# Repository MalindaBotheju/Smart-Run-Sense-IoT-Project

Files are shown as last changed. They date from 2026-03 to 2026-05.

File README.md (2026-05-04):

# 🏃‍♂️ SmartRunSense: IoT-Based Environmental Monitoring and Prediction System 

<p align="center">
  
  
  
  
  
  
</p>

## 📖 Overview
Outdoor running provides cardiovascular and mental health benefits, but exposes runners to thermodynamic and respiratory stresses caused by environmental conditions like heat, humidity, particulate matter, and gaseous pollutants. SmartRunSense is an Internet of Things (IoT) system designed to optimize performance and reduce physiological risks by helping runners make informed decisions about when and where to train. 

The system combines real-time environmental sensing, cloud-based data storage, machine learning predictive analytics, and a companion mobile application to provide both current and forecasted environmental conditions. 

---

## 🗺️ System Architecture Diagram
The diagram below illustrates the comprehensive project structure and data connections, organizing the system into four distinct logical layers: Edge Hardware (Wearable and Smart Pole nodes with their shared sensor suite), Cloud Ingestion & Storage (Firestore acting as the central data hub), Cloud Processing (Google Cloud Run executing the scikit-learn Random Forest forecasting engine), and the Application Layer (Mobile App visualizing live and forecasted conditions).

<p align="center">
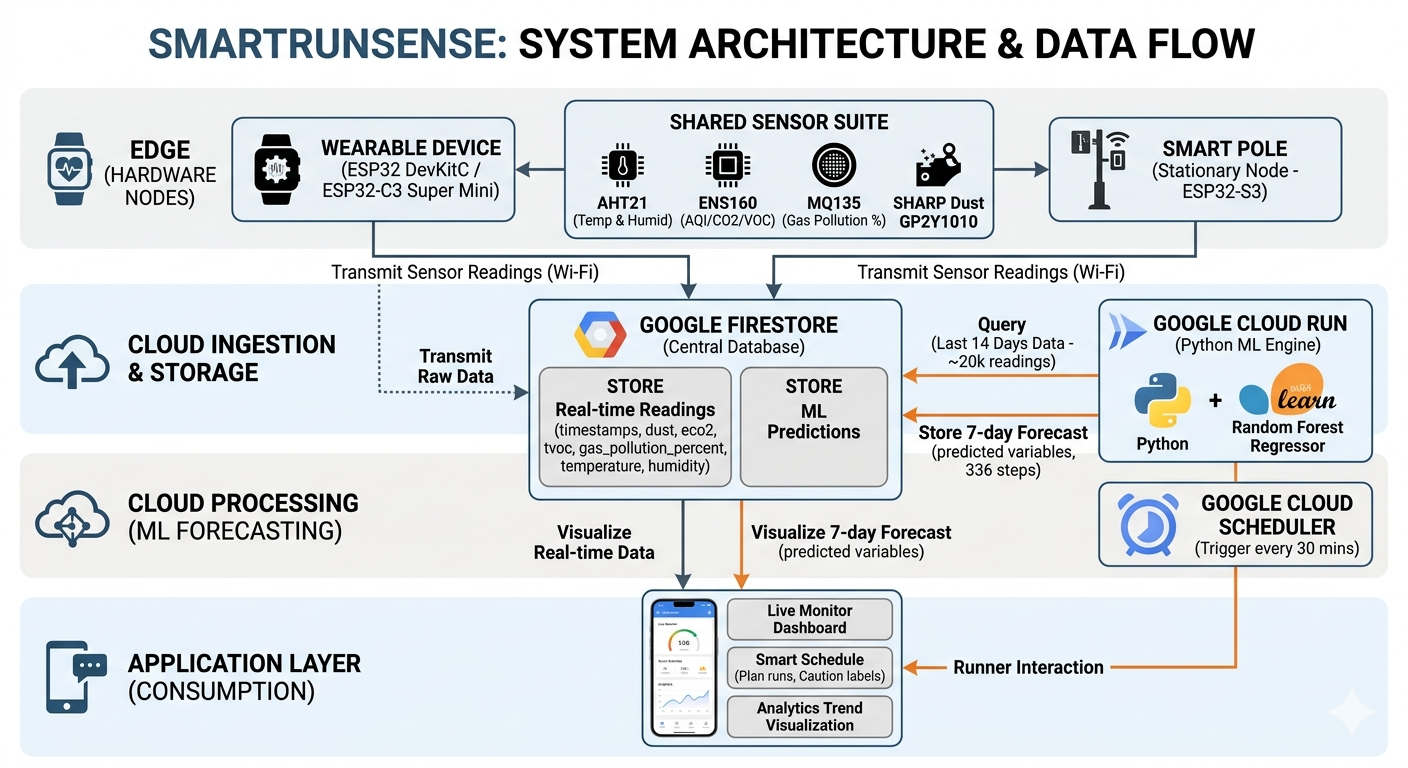
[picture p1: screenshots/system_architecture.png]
SmartRunSense System Architecture Diagram
  
</p>

---

## ✨ Key Features
* 📡 **Real-Time Monitoring:** Collects localized environmental data using wearable devices and stationary "Smart Poles".
* 🤖 **Machine Learning Forecasting:** Automatically predicts air quality and weather conditions 7 days into the future.
* 📱 **Mobile Application:** Provides a live sensor dashboards, historical analytics, and a "Smart Schedule" to plan the safest times to jog.

---

## 🛠️ Hardware Architecture

The system utilizes a dual-node hardware approach, consisting of mobile wearable devices and stationary monitoring nodes ("Smart Poles"). 

## ⌚ 1. Wearable Device
Designed for mobility, this node can be built using either an **ESP32 DevKitC** or a compact **ESP32-C3 Super Mini** microcontroller. 

<p align="center">
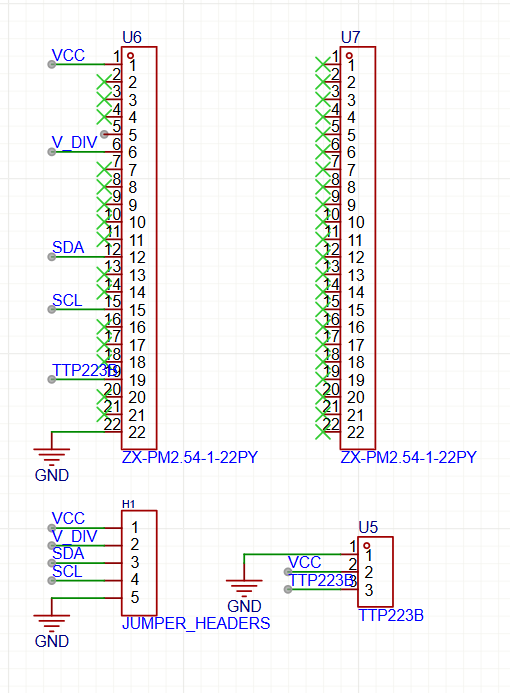
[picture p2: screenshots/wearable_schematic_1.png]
Wearable Schematic (Board-01)
  
  &nbsp;
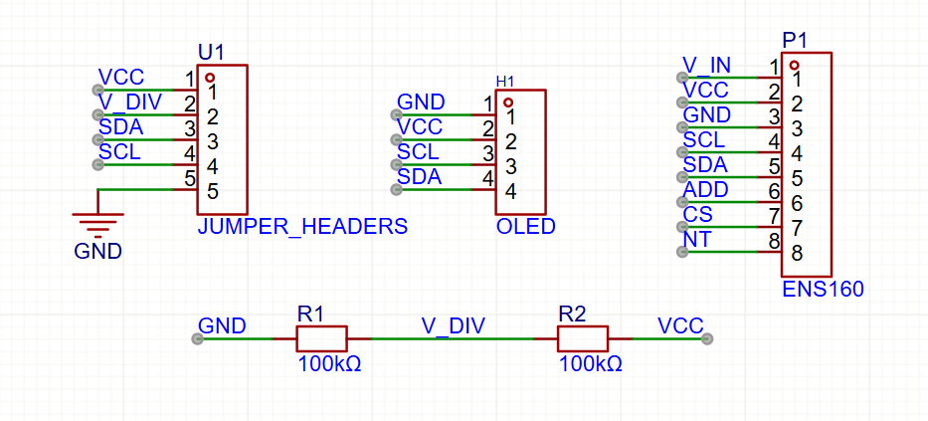
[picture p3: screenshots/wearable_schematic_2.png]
Wearable Schematic (Board-02)
  
  &nbsp;
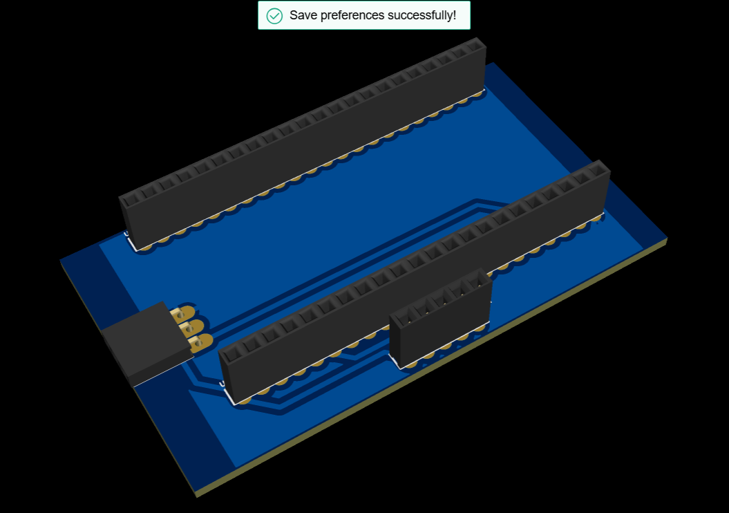
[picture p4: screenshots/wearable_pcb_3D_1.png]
Wearable PCB 3D View (Board-01)
  
  &nbsp;
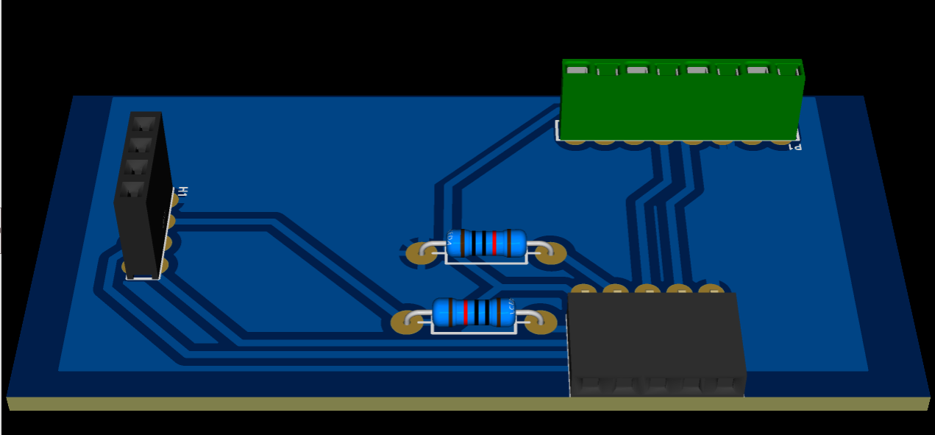
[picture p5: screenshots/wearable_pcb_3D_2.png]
Wearable PCB 3D View (Board-02)
  
  &nbsp;
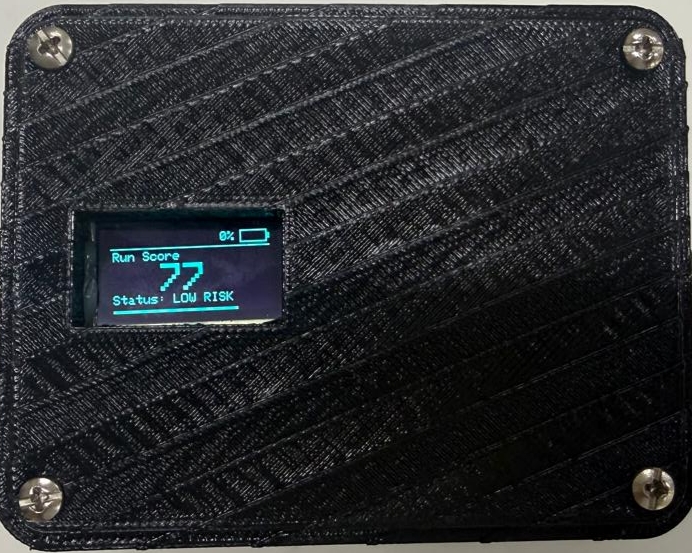
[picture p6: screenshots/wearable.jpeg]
Assembled Wearable Device
  
  &nbsp;
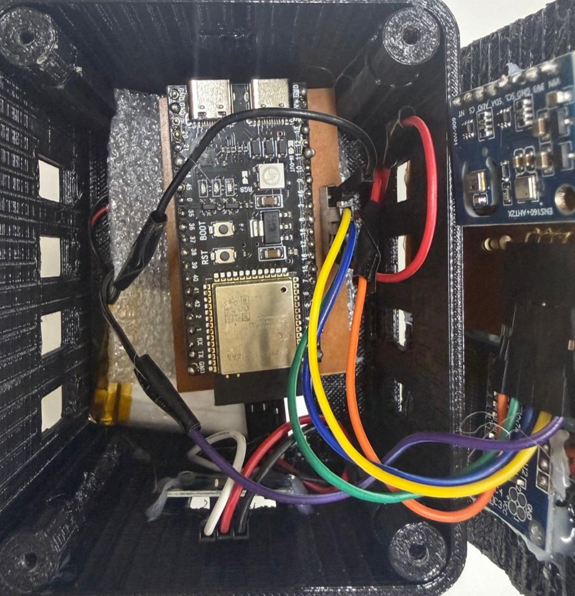
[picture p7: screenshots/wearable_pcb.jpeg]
Wearable PCB Layout
   
</p>

---

## 🗼 2. Smart Pole (Stationary Node)
Designed for continuous environmental monitoring at fixed locations (like running tracks or parks), this node is powered by a more robust **ESP32-S3** module.

<p align="center">
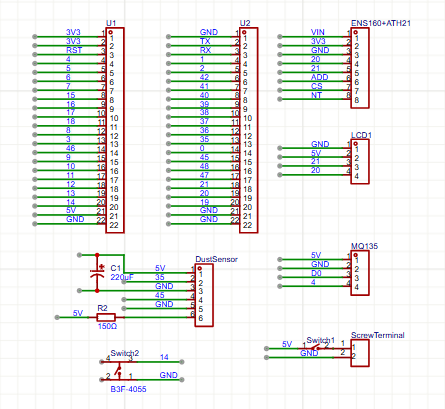
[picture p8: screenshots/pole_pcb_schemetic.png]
Smart Pole Schematic
  
  &nbsp;
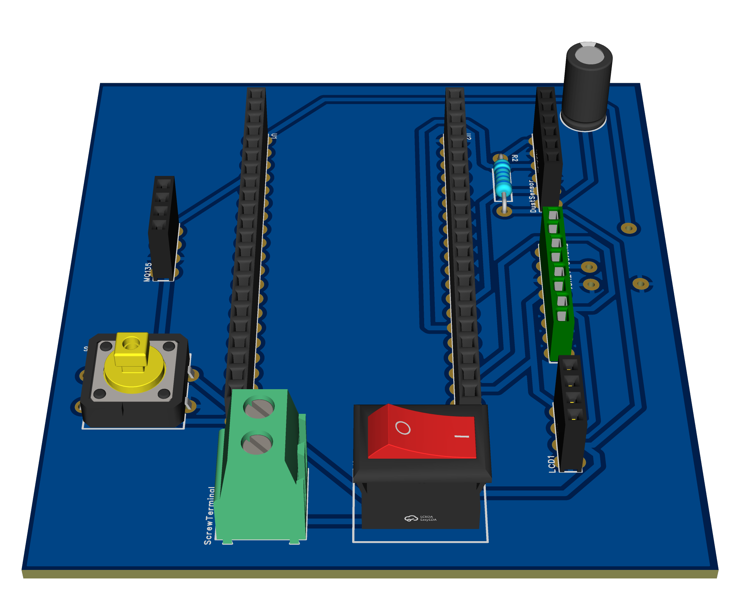
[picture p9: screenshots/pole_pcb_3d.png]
Smart Pole 3D PCB View
  
  &nbsp;
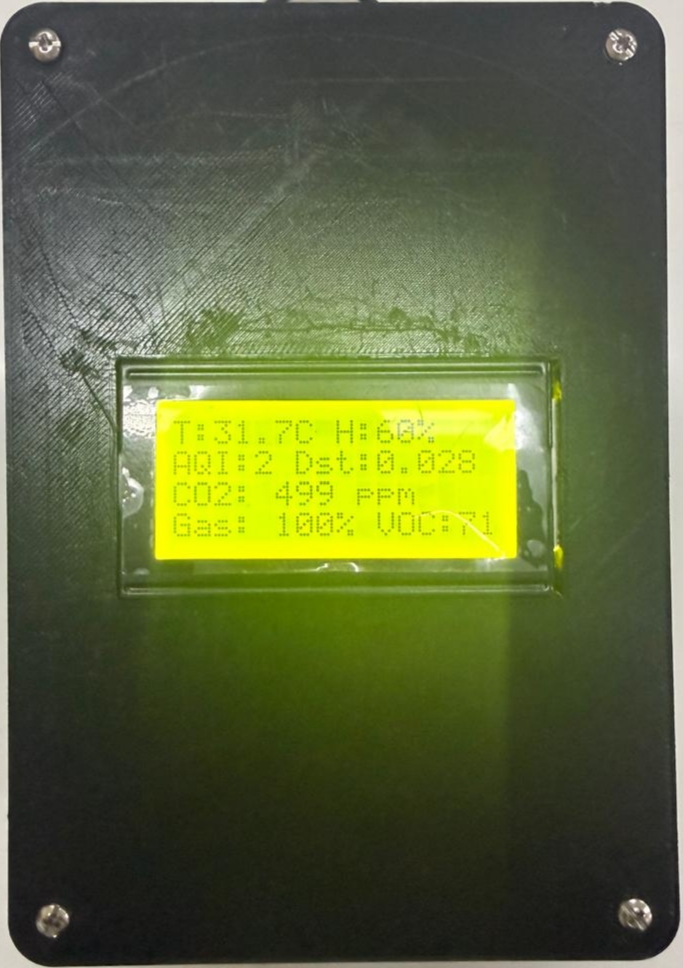
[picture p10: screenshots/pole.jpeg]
Assembled Smart Pole Device
  
  &nbsp;
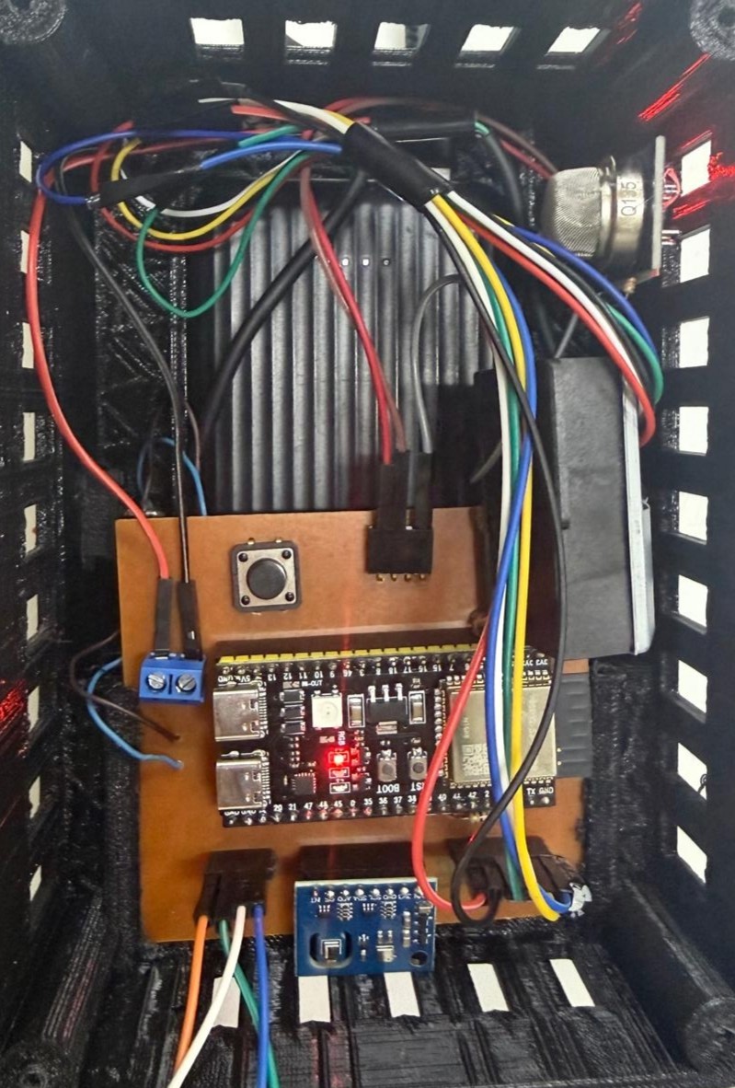
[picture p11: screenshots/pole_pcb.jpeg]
Smart Pole PCB Layout
  
</p>

---

Both the wearable and the Smart Pole devices interface with the following shared sensor suite and components:

## 🌡️ Sensors
* 🌬️ **ENS160 (Air Quality):** A self-calibrated digital sensor that measures the Air Quality Index (AQI), eCO2 (400-65,000 ppm), and Total Volatile Organic Compounds (TVOC).
* 💧 **AHT21 (Temperature & Humidity):** Factory-calibrated sensor measuring temperature (-40°C to +85°C) and relative humidity.
* 🏭 **MQ135 Gas Sensor:** An analog chemoresistive sensor used to measure general gas pollution intensity (0-100% scale), including Ammonia, NOx, Alcohol, Benzene, and Smoke. It uses a voltage divider circuit to safely interface the 5V sensor with the 3.3V ESP32.
* 💨 **SHARP GP2Y1010 Dust Sensor:** An optical sensor with an internal infrared LED and photodiode used to detect fine particles like dust, pollen, and smoke.

---

## 🧠 Machine Learning Forecasting Engine & ☁️ Cloud Infrastructure
A Python-based Cloud Run microservice acts as the forecasting engine.

* ⚙️ **Execution:** Triggered every 30 minutes by Google Cloud Scheduler.
<p align="center">
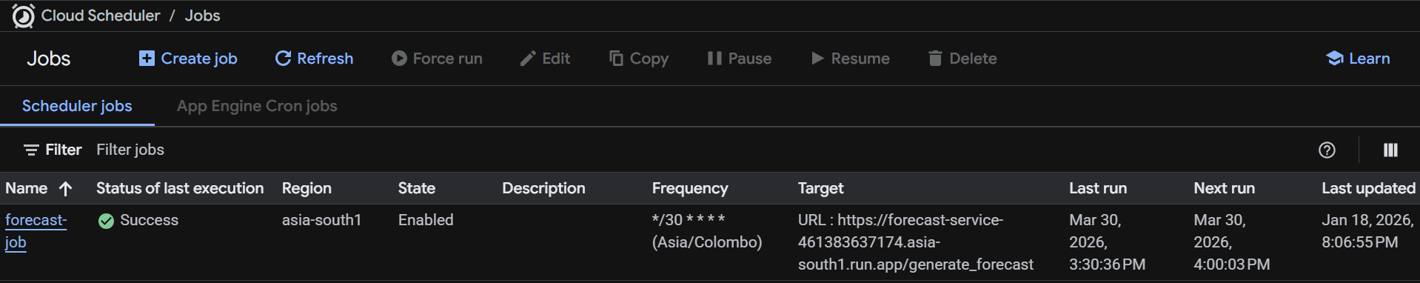
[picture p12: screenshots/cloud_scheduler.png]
Google Cloud Scheduler Configuration
  
</p>

* 📈 **Algorithm:** Uses a Random Forest Regressor (via scikit-learn) because it efficiently handles the highly non-linear nature of environmental data and trains in seconds using standard CPUs without requiring strict data scaling.
<p align="center">
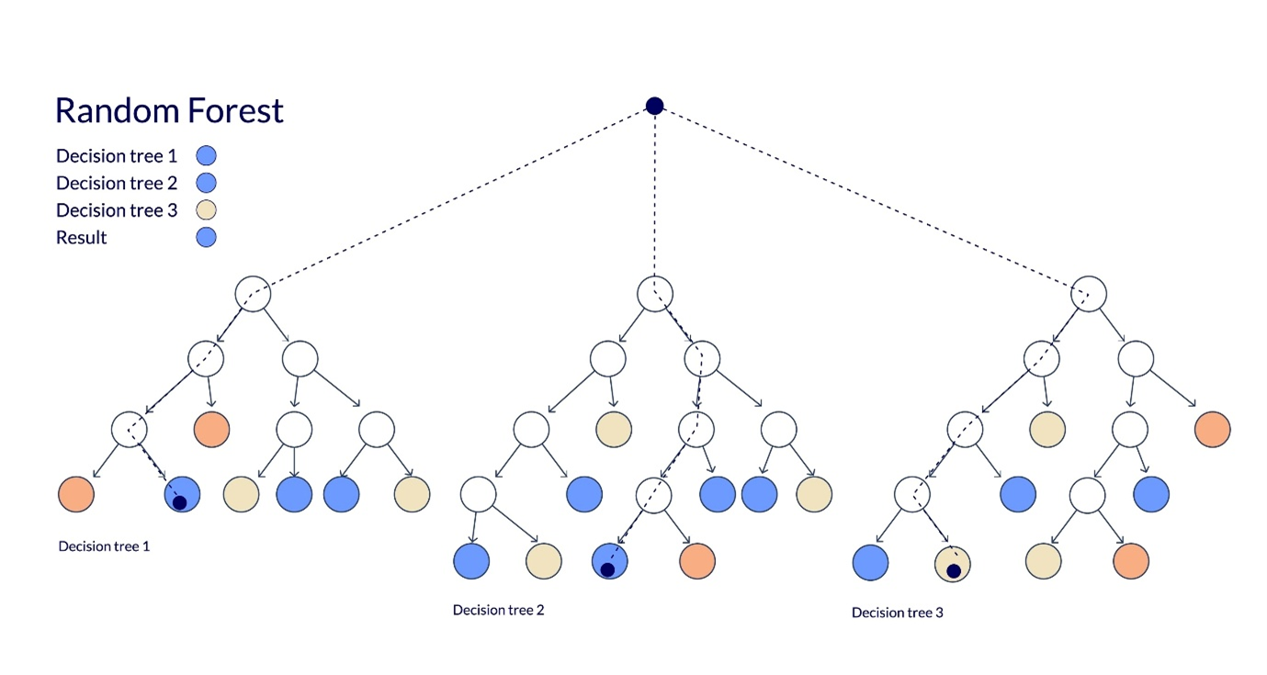
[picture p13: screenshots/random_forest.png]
Random Forest Algorithm Architecture
  
</p>

* 📊 **Data Scope:** The model queries the last 14 days (~20,000 readings) of data from Firestore to learn daily and weekly patterns.

* 🔮 **Output:** Generates predictions in 30-minute intervals for exactly 7 days into the future (336 distinct prediction steps per run). It predicts 7 variables simultaneously: Temperature, Humidity, Dust Density, AQI, TVOC, CO2, and Gas Pollution Percentage.

---

## 🗄️ Database
* 🔥 **Google Firestore:** Acts as the primary database, storing real-time sensor readings (e.g., timestamps, dust, eco2, tvoc, gas_pollution_percent, temperature, humidity) and the ML-generated predictions.
  
<p align="center">
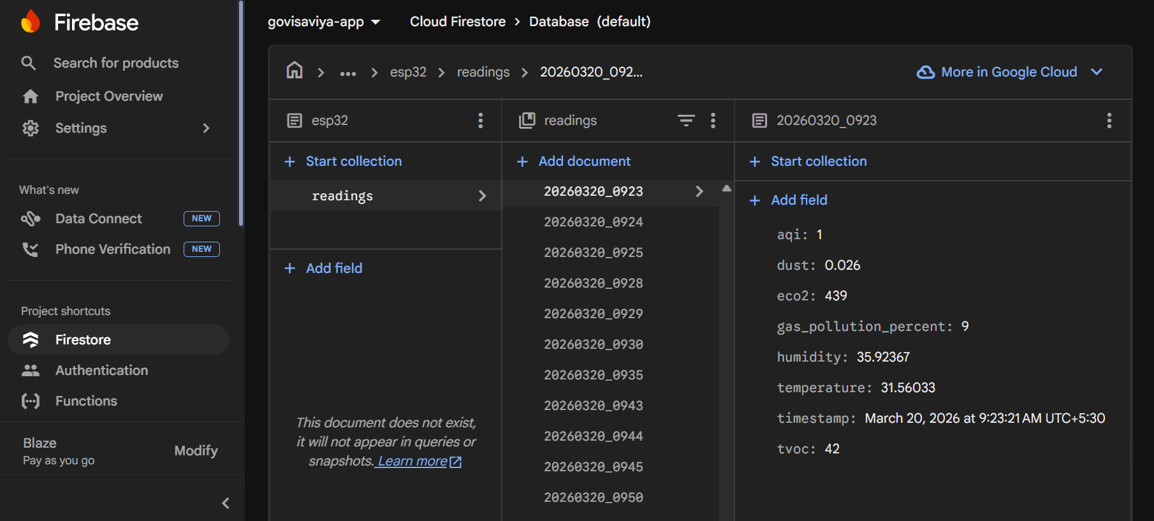
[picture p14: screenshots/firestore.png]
Google Firestore Database View
  
</p>

---

## 📱 Mobile Application
The mobile UI provides comprehensive data visualization for the end-user:

* 📊 **Live Monitor:** Displays real-time metrics including a summarized "Run Score" (e.g., 77% - LOW RISK) and individual sensor percentages.
* 📅 **Plan Your Activity (Smart Schedule):** Allows users to view upcoming days and flags specific time slots (e.g., "21:00 Caution Required - Pollution or heat levels elevated") to help them plan the best time to run.
* 📉 **Analytics:** Visualizes historical trends and insights, such as Dust and CO2 levels over time.
* 🌤️ **Forecast:** Displays the upcoming environmental predictions generated by the cloud microservice.

## 📸 App Screenshots

<p align="center">
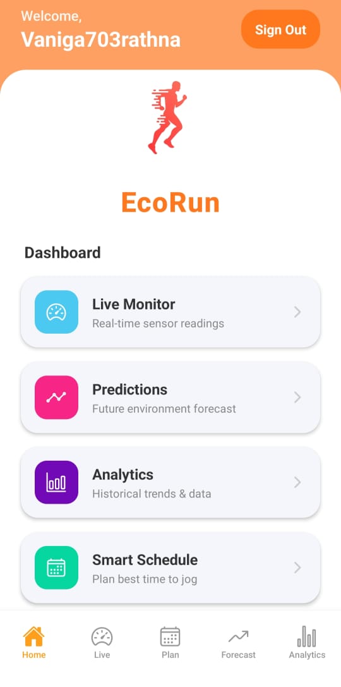
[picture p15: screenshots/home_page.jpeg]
Home Page
  
  &nbsp;
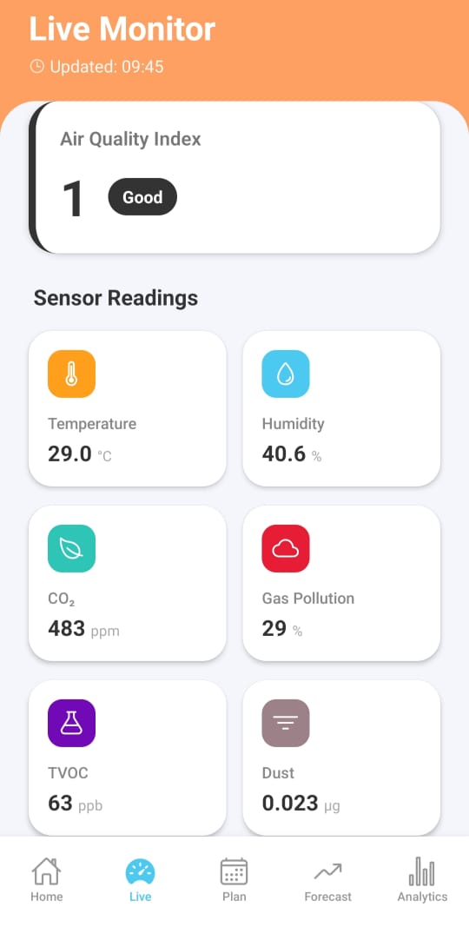
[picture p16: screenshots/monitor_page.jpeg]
Live Monitor
  
  &nbsp;
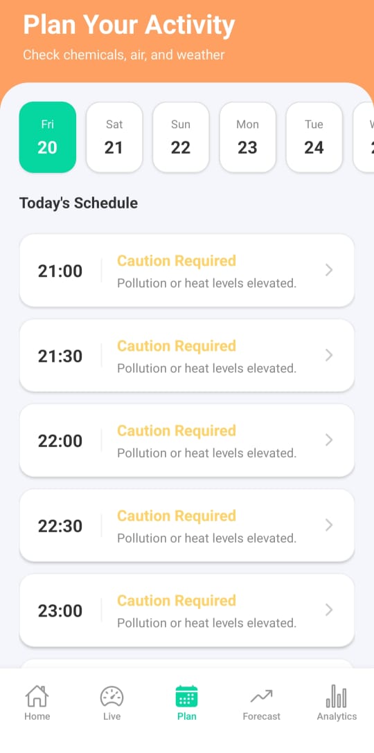
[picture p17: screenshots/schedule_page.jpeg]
Smart Schedule
  
  &nbsp;
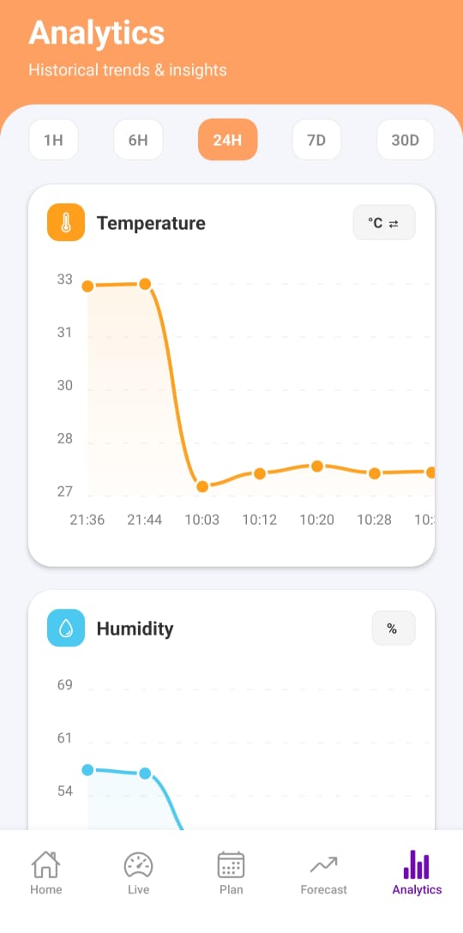
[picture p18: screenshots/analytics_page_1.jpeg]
Analytics Part 1
  
  &nbsp;
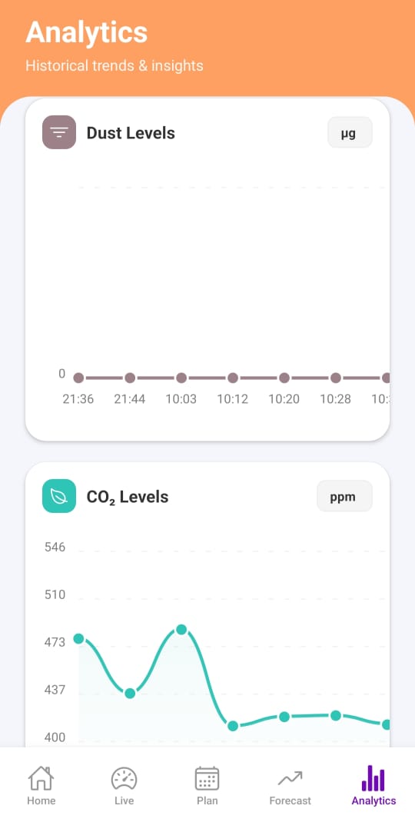
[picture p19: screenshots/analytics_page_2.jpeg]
Analytics Part 2
  
</p>

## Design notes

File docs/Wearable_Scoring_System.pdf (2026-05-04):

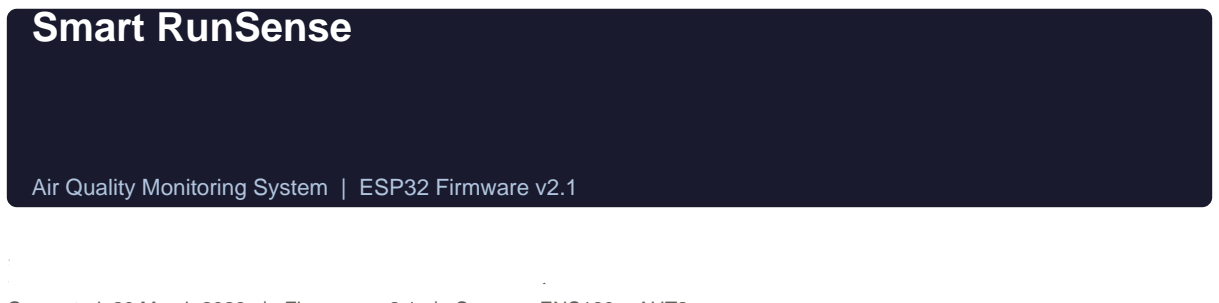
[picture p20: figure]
Smart RunSense

Air Quality Monitoring System | ESP32 Firmware v2.1
Scoring System Technical Report Mechanical Analysis of Air Quality Interpretation and Runner Score Computation
Generated: 20 March 2026 | Firmware: v2.1 | Sensors: ENS160 + AHT2x

### 1. System Overview

Smart RunSense is an embedded air quality monitoring system designed specifically for outdoor runners. Unlike standard Air Quality Index (AQI) systems that are calibrated for general population exposure over long periods, Smart RunSense computes a Runner Score — a real-time composite metric that accounts for both pollutant hazard and physical comfort conditions encountered during exercise. The score drives a five-band status classification displayed on the OLED screen and transmitted to Firebase Firestore.

Sensor | Parameter | Output Unit | Role in Score
ENS160 | eCO2 | ppm | Health AQI — primary
ENS160 | TVOC | ppb | Health AQI — primary
AHT2x | Temperature | °C | Comfort penalty
AHT2x | Humidity | % RH | Comfort penalty

Table 1 — Sensor inputs and their roles in the scoring pipeline.

### 2. Scoring Pipeline Architecture

The Runner Score is produced by a two-layer computation pipeline. Layer 1 evaluates atmospheric health through pollutant concentrations. Layer 2 applies a comfort-based scaling factor derived from temperature and humidity. The final score is bounded to [0, 100] and is intentionally asymmetric: poor air quality cannot be rescued by ideal comfort conditions, but extreme heat or humidity degrades performance even in chemically clean air.

Stage | Inputs | Output | Method
1a | eCO2 (ppm) | eCO2 Score | Piecewise linear
1b | TVOC (ppb) | TVOC Score | Piecewise linear
1c | Stage 1a + 1b | Health AQI | Dominant pollutant (min)
2a | Temperature (°C) | Temp Score | Piecewise linear
2b | Humidity (% RH) | Humidity Score | Piecewise linear
2c | Stage 2a + 2b | Comfort Score | Weighted blend 60/40
2d | Comfort Score | Comfort Multiplier | Linear scale [0.5 – 1.0]
3 | Health AQI x Multiplier | Runner Score | Multiplicative

Table 2 — Full computation pipeline with stage identifiers.

### 3. Individual Sensor Scoring Functions

### 3.1 eCO2 Score — getECO2Score(eco2)

Carbon dioxide equivalent (eCO2) is used as a proxy for overall indoor/outdoor air freshness and ventilation quality. The ENS160 derives eCO2 from metal oxide sensor readings, calibrated to the Adafruit AHT temperature and humidity sensor for temperature and RH compensation. Higher eCO2 concentrations indicate stale, poorly ventilated air which reduces oxygen availability for an exercising runner.

eCO2 Range (ppm) | Score | Condition
< 400 | 100.0 | Pristine — fresh outdoor air
400 – 5000 | Linear decrease from 100 to 0 | Moderate to severely polluted
> 5000 | 0.0 | Hazardous — do not run

Linear interpolation formula for 400 – 5000 ppm range:
eCO2 Score = max(0, 100 - ((eCO2 - 400) / 46.0))
Slope derivation: (100 - 0) / (5000 - 400) = 100 / 4600 = 0.02174 => 1/46.0 per ppm

### 3.2 TVOC Score — getTVOCScore(tvoc)

Total Volatile Organic Compounds (TVOC) represent a broad class of chemical pollutants including benzene, formaldehyde, and other volatile hydrocarbons. Elevated TVOC is associated with traffic emissions, industrial output, and off-gassing materials. During exercise, respiratory rate increases 10–20x, dramatically increasing pollutant intake, making TVOC a critical health factor for runners.

TVOC Range (ppb) | Score | WHO Classification
< 65 | 100.0 | Clean — no irritation
65 – 2200 | Linear decrease from 100 to 0 | Moderate to very high pollution
> 2200 | 0.0 | Extreme — hazardous exposure

Linear interpolation formula for 65 – 2200 ppb range:
TVOC Score = max(0, 100 - ((TVOC - 65) / 21.35))
Slope derivation: 100 / (2200 - 65) = 100 / 2135 = 0.04684 => 1/21.35 per ppb

### 4. Health AQI — Dominant Pollutant Model

The Health AQI does not average the two pollutant scores. Instead, it takes the strict minimum — the dominant pollutant model. This mirrors the methodology used by the US EPA's official AQI standard, where the overall air quality is determined by whichever single pollutant is worst.
Health AQI = min( eCO2 Score, TVOC Score )
Rationale: If eCO2 is excellent (Score = 95) but TVOC is dangerously high (Score = 12), averaging would produce a misleadingly acceptable result of 53.5. The dominant pollutant model correctly yields 12, accurately reflecting the hazardous chemical exposure the runner would experience.

### 5. Comfort Layer — Temperature and Humidity

### 5.1 Temperature Score — getTempScore(temp)

The optimal running temperature range is defined as 10 – 20°C based on exercise physiology research showing minimal cardiovascular strain and optimal thermoregulation in this window. Outside this range, the body expends additional energy on thermal regulation, reducing performance and increasing cardiac load.

Temperature Range | Score Formula | Physiological Rationale

10 – 20°C | 100.0 (flat) | Optimal running range
0 – 10°C | 50 + (T x 5.0) | Cold stress — muscle inefficiency
20 – 40°C | max(0, 100 - (T-20)x5) | Heat stress — hyperthermia risk
< 0°C or > 40°C | 0.0 | Extreme — dangerous to run

### 5.2 Humidity Score — getHumScore(hum)

Relative humidity directly affects the body's ability to cool itself through sweat evaporation. At humidity above 60%, sweat evaporation efficiency drops significantly, impairing thermoregulation. Below 40%, the air is too dry, increasing respiratory tract stress, dehydration risk, and airway irritation during heavy breathing.

Humidity Range | Score Formula | Effect
40 – 60% RH | 100.0 (flat) | Optimal evaporative cooling
10 – 40% RH | (H - 10) x 3.33 | Increasing dryness stress
60 – 90% RH | max(0, 100-(H-60)x3.33) | Decreasing sweat efficiency
< 10% or > 90% | 0.0 | Extreme — dangerous conditions

### 5.3 Comfort Score and Multiplier

Temperature and humidity scores are blended into a single Comfort Score using a weighted average that gives greater priority to temperature (60%) over humidity (40%), consistent with physiological evidence that ambient temperature is the stronger determinant of running performance degradation.
Comfort Score = (Temp Score x 0.6) + (Humidity Score x 0.4)
The Comfort Score is then converted to a multiplicative penalty factor — the Comfort Multiplier — which ranges from 0.5 (worst possible comfort) to 1.0 (perfect comfort). This multiplier is applied to the Health AQI.
Comfort Multiplier = 0.5 + (Comfort Score / 200.0)
At Comfort Score = 0: Multiplier = 0.5 (50% penalty — maximum degradation) At Comfort Score = 100: Multiplier = 1.0 (no penalty — perfect conditions)

### 6. Final Runner Score Computation

The Runner Score is the product of the Health AQI and the Comfort Multiplier:

### Runner Score = Health AQI x Comfort Multiplier

Expanding fully:
Runner Score = min(eCO2_Score, TVOC_Score) x [ 0.5 + (((Temp_Score x 0.6) + (Hum_Score x 0.4)) /
200) ]
Design Property | Behaviour | Why it Matters
Asymmetric penalty | Comfort cannot improve Health AQI above its raw value Prevents false reassurance in polluted environments
Dominant pollutant | Worst pollutant dictates Health AQI entirely | One toxic gas negates clean air elsewhere
Max comfort penalty | Even perfect air scores at most 50 in extreme heat/humidity Physiological limits respected regardless of air purity
Bounded output | Score always in [0, 100] | Consistent display and status classification

Table 3 — Key design properties of the Runner Score formula.

### 7. Status Classification Bands

The Runner Score is mapped to one of five status labels displayed on the OLED screen and stored in Firestore. The thresholds are calibrated to reflect real running safety guidelines rather than generic AQI categories:

DANGEROUS | UNSAFE | LIMIT | CAUTION | SAFE
0 | 30 | 50 | 70 | 85 | 100
Figure 1 — Runner Score status band distribution (0 – 100).
Score Range | Status | Recommended Action
85 – 100 | SAFE | Ideal conditions. Full training recommended.
70 – 84 | CAUTION | Acceptable. Monitor intensity, stay hydrated.
50 – 69 | LIMIT | Reduce intensity. Limit exposure time.
30 – 49 | UNSAFE | Avoid strenuous exercise. Short walks only.
0 – 29 | DANGEROUS | Do not run. Remain indoors if possible.

### 8. Worked Example — Typical Sri Lankan Afternoon Run

The following example demonstrates the full computation pipeline using realistic sensor values for a roadside urban run in Colombo at 3 PM:

Parameter | Sensor Reading | Sub-score
eCO2 | 780 ppm | Score = max(0, 100 - (780-400)/46.0) = 91.7
TVOC | 310 ppb | Score = max(0, 100 - (310-65)/21.35) = 88.5
Temperature | 32°C | Score = max(0, 100 - (32-20)x5) = 40.0
Humidity | 78% RH | Score = max(0, 100 - (78-60)x3.33) = 40.1

Step-by-step computation:
Health AQI = min(91.7, 88.5) = 88.5
Comfort Score = (40.0 x 0.6) + (40.1 x 0.4) = 24.0 + 16.04 = 40.04
Comfort Multiplier= 0.5 + (40.04 / 200.0) = 0.700
Runner Score = 88.5 x 0.700 = 61.95 → Status: LIMIT

Interpretation: Although the air pollutant levels are relatively acceptable (Health AQI = 88.5), the extreme heat and high humidity of a Colombo afternoon impose a 30% comfort penalty, pulling the final score into the LIMIT zone. The system correctly advises the runner to reduce intensity — a medically sound recommendation given the combined thermal and chemical stress.

### 9. Sensor Compensation

The ENS160 TVOC and eCO2 readings are temperature and humidity compensated in firmware before score calculation. The AHT2x readings are fed back into the ENS160 at each measurement cycle:

ens160.setTempCompensation(temp.temperature); ens160.setRHCompensation(hum.relative_humidity);
This ensures that elevated temperature does not artificially inflate eCO2 and TVOC readings, which is a common error in uncompensated metal oxide sensor deployments. All scores are therefore computed on environmentally corrected concentration values.

### 10. Data Output and Storage

Every 60 seconds, a complete measurement document is written to Google Firestore under the path sensor_data/esp32_0/readings/{YYYY-MM-DDTHH:MM}. The document includes all raw sensor values, all intermediate scores, the final Runner Score, and battery telemetry:

Firestore Field | Type | Description
temperature | double | AHT2x temperature (°C)
humidity | double | AHT2x relative humidity (%)
aqi | int | ENS160 native AQI index (1–5)
eco2 | int | Compensated eCO2 (ppm)
tvoc | int | Compensated TVOC (ppb)
runner_aqi | double | Computed Runner Score (0–100)
battery_voltage | double | Measured battery voltage (V)
battery_percent | int | Derived battery percentage (%)
timestamp | string | ISO 8601 timestamp (local time +05:30)
Smart RunSense | ESP32 Firmware v2.1 | Sensors: ENS160 + AHT2x | Scoring Engine: calculateRunnerAQI() | Report generated 20 March
2026

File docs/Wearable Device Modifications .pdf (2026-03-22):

# SmartRunSense

## Wearable Device

ESP32 DevKitC vs ESP32-C3 Super Mini

## Shared Components: Sensors, Display & Battery

The following components are identical in both wearable builds. Specifications and usage are the same regardless of which microcontroller board is selected.

Component | Specification | DevKitC build | C3 Super Mini build

Sensors

ENS160 Air quality sensor | eCO₂: 400–65,000 ppm TVOC: 0–65,000 ppb AQI index · I²C · LGA-9 · 3×3×0.9 mm | ✓ Same | ✓ Same
AHT21 Temp + humidity | ±0.3°C, range −40 to +85°C ±2% RH · I²C · SMD · 3×3×0.8 mm | ✓ Same | ✓ Same
SSD1306 OLED 0.49" display | 64×32 px · I²C · ~14×11 mm glass Timeout off after 5 s, wake on touch | ✓ Same | ✓ Same

Power & Charging

LiPo battery 3.7 V rechargeable | 200 mAh · 3.7 V · JST SH 1.0 mm ~30×15×4 mm cell | 200 mAh | 200 mAh
MCP73831T LiPo charger IC | 100 mA single-cell · SOT-23-5 2.9×1.6 mm · USB-C input | ✓ Same | ✓ Same
USB-C connector Charge + flash | GCT USB4085 mid-mount 8.9×3.5 mm SMD | ✓ Same | ✓ Same

Touch Interface

Capacitive touch
User input button

Native ESP32 GPIO touch channel Exposed copper pad on PCB
surface

✓ Built-in GPIO ✓ Built-in GPIO

## Microcontroller Board Comparison

Direct comparison of the ESP32 DevKitC development board against the ESP32-C3 Super Mini for use in the SmartRunSense wearable. Green cells indicate the better choice for a wearable application; amber cells indicate where the DevKitC has an advantage.

Feature | ESP32 DevKitC | ESP32-C3 Super Mini

Hardware Specs

Board size | 55.3 × 28.0 mm | 22.5 × 18.0 mm
Board area | 1,548 mm² | 405 mm²
Processor | Xtensa LX6 dual-core | RISC-V single-core
Clock speed | 240 MHz | 160 MHz
Flash memory | 4 MB | 4 MB
SRAM | 520 KB | 400 KB
Usable GPIOs | 38 pins | 11 pins

Wireless

Wi-Fi | 802.11 b/g/n (Wi-Fi 4) | 802.11 b/g/n (Wi-Fi 4)
Bluetooth | BLE 4.2 | BLE 5.0
RF certification | FCC / CE (board) | FCC / CE (module)
Antenna | PCB trace on WROOM module | Built-in PCB trace

Power

Active current | ~80–120 mA | ~20–30 mA
Light sleep | ~10–15 mA | ~5 µA (deep sleep)
Est. battery life | ~3–5 h / 200 mAh | ~10–14 h / 200 mAh
Native USB OTG | No — needs CH340 bridge | Yes

Assembly & Soldering

Soldering method | Pin headers — plug in | SMD castellated pads
Support circuits needed | None — all on board | LDO + buttons + caps
Prototype difficulty | Very easy | Moderate
Production suitability | Poor — redundant parts | Good — compact custom PCB

GPIO Sufficiency for SmartRunSense

I²C (SDA + SCL) | ✓ 2 pins used | ✓ 2 pins used

Feature | ESP32 DevKitC | ESP32-C3 Super Mini
OLED RST + DC | ✓ 2 pins used | ✓ 2 pins used
Capacitive touch | ✓ 1 pin used | ✓ 1 pin used
Total GPIOs needed | 5 of 38 used | 5 of 11 used
Room for expansion | 33 GPIOs spare | 6 GPIOs spare

## Enclosure Box Size Comparison

Estimated enclosure dimensions for the assembled wearable device including board, sensors, OLED display, battery, and wiring clearance. Based on DevKitC box dimensions of 88 × 68 × 55 mm as the baseline.

Dimension | DevKitC wearable box | C3 Super Mini box | Saving

Enclosure Outer Dimensions

Length (longest side) | 88 mm | 55 mm | −33 mm (−37%)
Width | 68 mm | 58 mm | −10 mm (−15%)
Depth / height | 55 mm | 45 mm | −10 mm (−18%)

Volume & Area

Footprint area (L × W) | 5,984 mm² | 3,190 mm² | −2,794 mm² (−47%)
Total volume (L × W × D) | ~328,000 mm³ | ~143,550 mm³ | −184,450 mm³ (−56%)

What Drives the Size Reduction

Board length contribution | 55.3 mm board | 22.5 mm board | −32.8 mm saved
OLED glass (unchanged) | ~14 mm wide | ~14 mm wide | No change
Battery (unchanged) | ~30 × 15 mm | ~30 × 15 mm | No change
Wiring clearance | ~15 mm each side | ~10 mm each side | −5 mm / side
Depth (thinner layout) | 55 mm | ~45 mm | Flatter battery fit possible

Wrist Wearability

Fits standard watch case? | No — 88 mm too long | Marginal — 55 mm is borderline | Closer to wearable size
Recommended enclosure type | Belt clip / armband | Wrist band / armband | Better form factor

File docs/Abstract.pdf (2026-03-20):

## SmartRunSense: An IoT Based Environmental Monitoring and Prediction System for Safer Outdoor Running

## Abstract

Outdoor running is one of the most accessible and widely practiced forms of physical exercise, providing cardiovascular and mental health benefits. However, the thermodynamic and respiratory stresses experienced during outdoor training are strongly influenced by environmental conditions. Ambient temperature and humidity determine the rate of heat exchange between the body and the surroundings, while airborne particulate matter and gaseous pollutants alter respiratory efficiency and gas exchange (Brook et al., 2010; WHO, 2018). Understanding these interactions is critical for optimizing performance and reducing physiological risk during sustained exercise. Despite these risks, runners often rely on general weather forecasts that do not accurately represent localized environmental conditions at specific training tracks or open-air exercise spaces, which may expose them to heat stress, dehydration, or respiratory irritation without their knowledge (Li et al., 2019).

To address this challenge, SmartRunSense proposes an Internet of Things (IoT) based environmental monitoring and prediction system that enables runners to make informed decisions about when and where to train. The system combines real time environmental sensing, cloud based data storage, predictive analytics using machine learning, and a mobile application to provide both current and forecasted environmental conditions. By continuously monitoring atmospheric variables and analyzing their temporal patterns, the system identifies safer time periods for outdoor running and supports optimized training schedules.

The environmental monitoring component consists of stationary sensing units, referred to as Smart Poles, which collect high resolution data from multiple environmental sensors. Each Smart Pole is built around an ESP32 microcontroller, chosen for its Wi-Fi communication capabilities and low power consumption. Temperature and relative humidity are measured using an AHT21 digital sensor, enabling assessment of thermoregulatory stress via sweat evaporation efficiency. Air quality is evaluated using an ENS160 sensor, which provides measurements for Air Quality Index (AQI), equivalent carbon dioxide (eCO₂), and Total Volatile Organic Compounds (TVOC). Additional gas pollutants are estimated using a MQ135 sensor, while particulate concentration is measured using an optical dust sensor (GP2Y1010AU0F / DSM501A), which detects infrared light scattering caused by suspended particles. This multi-sensor setup captures a comprehensive environmental profile relevant to both thermodynamics and respiratory exposure (Kumar et al., 2015).

Data collected by the Smart Poles are transmitted via Wi-Fi to a cloud database (Google Firebase Firestore), where they are timestamped and stored. These continuous datasets enable the system to perform predictive analysis using a Random Forest regression model, trained on historical environmental data to forecast temperature, humidity, dust concentration, AQI, and pollutant levels at 30-minute intervals for up to seven days. By analyzing temporal features such as hour of the day and day of the week, the model identifies patterns and predicts periods when environmental conditions are safer for outdoor activity.

In parallel, SmartRunSense incorporates a wearable device that provides runners with real-time, localized environmental information in their breathing zone. The wearable is built on an ESP32-S3 microcontroller with integrated Wi-Fi and Bluetooth Low Energy (BLE), combined with an ENS160 air-quality sensor and AHT21 temperature and humidity sensor. The device measures eCO₂, TVOC, temperature, and humidity near the runner and displays these values on a compact OLED screen. A simple touch-based interface allows users to check current environmental conditions at a glance. Unlike the Smart Poles, the wearable does not transmit data to the cloud; it functions as an awareness tool, providing immediate feedback on the air the runner is breathing.

The SmartRunSense mobile application consolidates data from the Smart Poles and predictive model, allowing users to visualize both current environmental measurements and forecasted conditions. Parameters such as temperature, humidity, AQI, dust levels, and pollutant concentrations are presented in a user-friendly format. The app highlights recommended running periods based on predicted environmental safety, enabling runners to plan training sessions while minimizing exposure to heat stress or air pollutants.

By integrating environmental physics principles, IoT sensing, and predictive analytics, SmartRunSense offers a comprehensive system that supports safer outdoor exercise. It enables runners to make data driven decisions based on both the current conditions in their immediate environment and predictions of how these conditions may change over time. This combination of stationary monitoring, wearable awareness, machine learning based forecasting, and mobile visualization demonstrates the potential of technology driven environmental assessment to improve athletic safety and performance in outdoor activities.

## References

1. Brook, R. D., Rajagopalan, S., Pope III, C. A., Brook, J. R., Bhatnagar, A., Diez-Roux, A. V., ... & Kaufman, J. D. (2010). Particulate matter air pollution and cardiovascular disease: An update to the scientific statement from the American Heart
Association. Circulation, 121(21), 2331–2378.
2. World Health Organization (WHO). (2018). Air pollution and child health: Prescribing clean air. Geneva: WHO.
3. Li, X., et al. (2019). Wearable environmental sensing for personalized exposure assessment. Sensors, 19(11), 2573.
4. Kumar, P., et al. (2015). The rise of low-cost sensing for managing air pollution in cities. Environment International, 75, 199–205.

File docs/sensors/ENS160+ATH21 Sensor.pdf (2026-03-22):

ENS160 + ATH21 sensor module

This is a modern digital sensor and it handles the calibration internally. So, it is a selfcalibrated sensor.

Here is the explanation how the both parts calibrate themselves:

1. The AHT21 (Temp & Humidity): "Factory Memory"
- The Method: Factory Calibration.
- How it works: Before the sensor leaves the factory, the manufacturer tests it in a perfect climate chamber. They figure out its tiny physical errors, create a correction formula, and permanently save that formula inside the sensor's chip. Every time it measures the air, it does the math to correct its own errors before sending the data to the code.
2. The ENS160 (Air Quality): "Remembering Fresh Air"
- The Method: Automatic Baseline Correction (ABC).
- How it works: It continuously monitors the air over several days and looks for the lowest pollution level it can find (like when the room is empty or a window is open). It assumes this lowest point is "clean, fresh air" and uses it as its new baseline (zero point) to measure everything else against.

Even though it self-calibrates, the ENS160 requires a 3-minute warm-every time it turns on to heat its plate, and a 24-hour initial "burn-in" when brand new to find its first true baseline.

These are the measurements we take from this sensor;

- Temperature: Measured in Celsius.
- Humidity: Measured as a percentage (%).
- AQI: Air Quality Index. A standard 1-5 scale (1 being excellent, 5 being terrible) based on global air quality guidelines.
- CO2 (eco2): Equivalent Carbon Dioxide, measured in ppm (Parts Per Million).
- TVOC: Total Volatile Organic Compounds, measured in ppb (Parts Per Billion). This detects a massive range of indoor pollutants like fumes from cleaning products, paints, and perfumes.

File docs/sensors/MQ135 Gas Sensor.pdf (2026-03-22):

## MQ135 Gas Sensor

### 1. Sensor Overview and Purpose

The MQ135 is an analog chemoresistive gas sensor broadly sensitive to a range of polluting gases, including Ammonia (NH3), Nitrogen Oxides (NOx), Alcohol, Benzene, Smoke, and Carbon Dioxide (CO2). In this system, the MQ135 is used to measure General Gas Pollution Intensity on a normalized 0–100% scale.

The MQ135 requires a 5V power supply to heat its internal sensing layer. So, its analog output pin (A0) can output voltages ranging from 0.1V up to nearly 5.0V.

Because the ESP32-S3 microcontroller’s Analog-to-Digital Converter (ADC) pins are strictly limited to a maximum of 3.3V, directly connecting the sensor would risk hardware. To safely interface the sensor, a Voltage Divider circuit was implemented on the PCB. Using two resistors of equal value (R1 and R2 at 10kΩ each), the 5V signal is safely stepped down to a maximum of 2.5V before reaching the ESP32 GPIO pin. The ESP32 code then mathematically multiplies the measured voltage by 2 to reconstruct the true sensor output voltage.

### 2. Calibration Procedure (R0 Calculation)

According to the MQ135 datasheet, the resistance ratio (Rs/R0) in clean, fresh air is a constant 3.6.

- Step 1: Turn your device on and let it run for at least 30 minutes, because the sensor requires a warm-up period. When first powered on, the readings will fluctuate significantly until its internal temperature stabilizes.
- Step 2: Take your powered-on device outside into fresh air. Let it sit there for about 5 minutes to adjust to the outdoor air.
- Step 3: Over the next 5 to 10 minutes, record the Rs (Sensor Resistance) values from an Arduino code and take the average value of them.
- Step 4: Take that average Rs and simply divide it by 3.6 (the clean-air rule from the manufacturer's datasheet). We got the R0 as 33.62567 kΩ.

### 3. Calculate the “Gas Pollution Percentage”

The Fixed Parameters

- R0: The calibrated baseline resistance in clean air.
- R(load): This is the physical 10kΩ resistor soldered onto the back of the MQ135 module.
- a(PARA): 102.2 (A scaling number taken directly from the Ammonia/Smoke sensitivity curve in the MQ135 datasheet).

- b(PARB): 2.473 (A slope number taken directly from that exact same datasheet curve).

The equations used in the code

Equation 1: The ESP32’s analog pin reads the sensor as a digital number between 0 and 4095. The code must convert this back into a physical voltage (out of the 3.3V maximum).

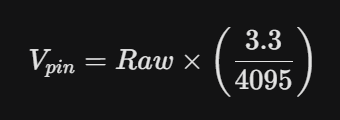
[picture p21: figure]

Equation 2: Because your PCB has two resistors dividing the voltage in half to protect the ESP32, the sensor's actual output is twice as high as what the ESP32 sees.

Equation 3: Finding the Current Sensor Resistance (Rs)

Now the code calculates the real-time electrical resistance of the chemical sensor (Rs). Since the MQ135 is powered by 5.0V, it uses the standard voltage divider formula alongside your R(load) parameter:

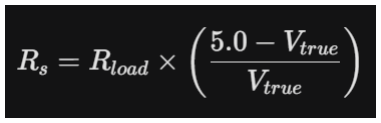
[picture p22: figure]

Equation 4: This is the core datasheet equation. The code takes the current air (Rs), divides it by your clean air memory (R0), and applies the datasheet curve parameters (a and b) to find the exact concentration of gas in Parts Per Million.

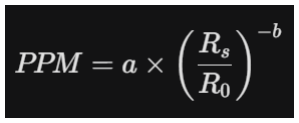
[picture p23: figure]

Equation 5: Finally, the code converts that PPM number into a 0% to 100% scale using a linear mapping formula (which Arduino handles using the map() function). If we define 0 PPM as 0% and 10 PPM as 100%:

Here is what the different output percentages actually mean:

- 0% to 10% (Fresh Air): The air is perfectly clean and fresh. The code calculates around 0 to 1 PPM.
- 20% to 40% (Mild Pollution): Trace amounts of general polluting gases have entered the air. The code calculates around 2 to 4 PPM.
- 50% to 70% (Poor Air Quality): There is a strong, distinct presence of smoke or chemical gas in the air. The code calculates around 5 to 7 PPM.
- 80% to 100% (Toxic Level): The air is heavily polluted. The code calculates around 8 to 10 PPM.

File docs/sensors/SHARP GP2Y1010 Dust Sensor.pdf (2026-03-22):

## SHARP GP2Y1010 Dust Sensor

### 1. Sensor Overview

The SHARP GP2Y1010 is an optical air quality sensor designed to detect very fine particles like dust, pollen, and cigarette smoke. The sensor detects these using an internal infrared (IR) LED and a photodiode, which are arranged diagonally across a hollow airflow chamber. When air enters the sensor's chamber, the internal IR LED illuminates it. Clean air allows the light to pass through without interference. If dust particles are present, they scatter the light toward the photodiode, which then measures the intensity of the scattering and produces an analog voltage proportional to the amount of dust.

### 2. Calibrate the sensor

Place your active sensor inside a sealed, clean container. Let it sit for 3 to 5 minutes so any trapped dust physically settles to the floor of the box. Watch the live voltage output on the serial monitor screen from the relevant Arduino code. It will slowly drop and eventually bottom out at a completely stable number. That lowest stable number is your calibrated V(threshold). The value we got as V(threshold) was 0.1V.

### 3. Taking the Dust Readings

Even though the sensor is powered by 5V, the SHARP datasheet shows its analog output rarely goes above 3.5V even in extremely heavy dust. Because 3.5V is very close to the ESP32's 3.3V limit, we just wire it directly without a voltage divider to ESP32.

The IR LED inside the sensor cannot be left on continuously, as it draws too much power, heats up, and degrades. According to the manufacturer's datasheet, it must be pulsed on and off in strict 10-millisecond cycles. In the Arduino code, it manually controls this exact sequence using “delayMicroseconds()”.

The equations used;

Equation 1: Converting the Digital Number to Voltage

Equation 2: The Linear Dust Conversion

The SHARP sensor does not output 0.0V in clean air. It has a natural resting voltage (often called the no-dust voltage). We took it as 0.1V.

- V(pin): The current voltage reading.
- V(threshold): The custom zero-dust baseline.
- 0.5: The datasheet voltage scaling factor.
- 1000: A multiplier used to scale the output into a more readable high-precision format (often mapping into (ug/m^3).

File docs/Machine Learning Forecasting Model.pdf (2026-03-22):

## Machine Learning Forecasting Engine (Cloud Run Microservice)

### 1. System Overview

We built a Python program hosted on Google Cloud that automatically runs every 30 minutes. It reads the most recent environmental data, trains a new AI model on the spot, predicts future conditions, and uploads those results to our Firestore database.

### 2. Data Scope and Forecast Horizon

- Historical Data Used (The Input): The model queries the last 20,000 readings from Firestore, which roughly equates to the last 14 days of historical data. This 2-week window is specifically chosen to allow the model to learn daily patterns (e.g., temperatures rising at noon) as well as weekly cycles (e.g., weekends having different pollution levels than weekdays).
- Forecast Timeframe (The Output): The model predicts exactly 7 days into the future.
- Resolution: Predictions are generated in 30-minute intervals, resulting in 7 × 48 = 336 distinct prediction steps per execution.

### 3. The Variables (Features & Targets)

The model analyzes and predicts seven distinct environmental variables simultaneously:

1) Temperature
2) Humidity
3) Dust Density
4) AQI (Air Quality Index)
5) TVOC (Total Volatile Organic Compounds)
6) CO2 (eCO2-Equivalent Carbon Dioxide)
7) Gas Pollution Percentage (from the MQ135)

Each prediction is generated with the data and the time.

### 4. The Chosen Algorithm: Random Forest Regression

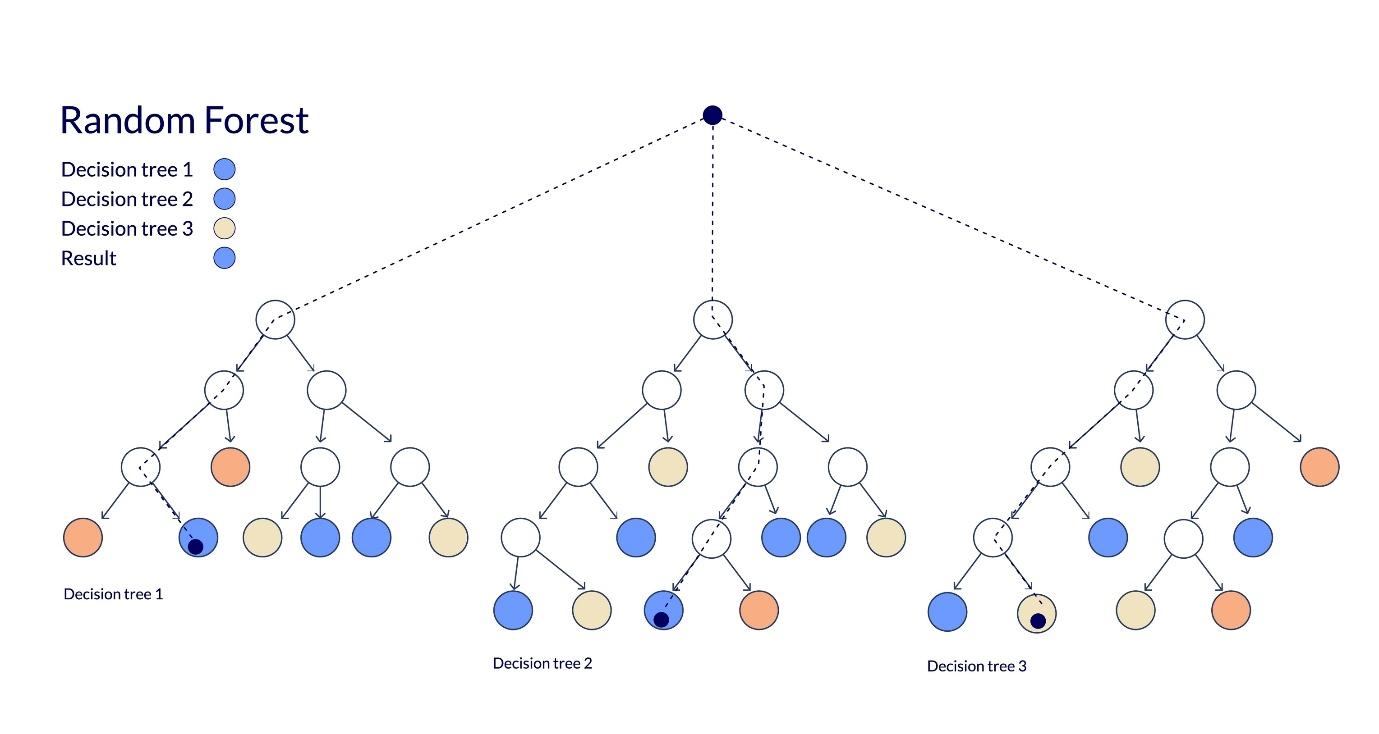
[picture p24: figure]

The code uses Random Forest Regressor from the scikit-learn library as the model. Random Forest is an ensemble learning method that builds dozens of "Decision Trees" during training and averages their predictions to output a highly accurate final result.

Why Random Forest was chosen over other algorithms:

- Handling Non-Linearity: Environmental data is highly non-linear. Linear Regression fails here, but Random Forest handles non-linear spikes exceptionally well.
- Compute Efficiency for Cloud Run: While Deep Learning models like LSTMs (Long Short-Term Memory networks) are great for time-series, they require heavy computing power, GPUs, and long training times. Random Forest trains in a matter of seconds using standard CPUs, making it perfect for a lightweight, cost-effective Cloud Run environment that triggers every 30 minutes.
- No Data Scaling Required: Neural networks require all data to be strictly normalized (scaled between 0 and 1). Random Forests do not care about the scale of the data, meaning we can feed raw Temperature (e.g., 30°C) and raw eCO2 (e.g., 400ppm) into the exact same model without complex pre-processing.

### 5. The Crucial Mechanism: How the Model Predicts the Future

The most critical part of this architecture is how it handles the time-series forecasting. It uses a technique called Autoregressive Recursive Forecasting.

Here is the exact step-by-step mechanism the code follows to predict the future:

Step 1: Resampling the Data;

- Sensor data can be messy and irregular. To fix this, our system automatically put the raw data into neat 30-minute intervals for the 14 days, giving the AI a clean and consistent timeline to learn from.
Step 2: Training 7 Parallel Models;

The code does not train just one model. It initializes a loop and trains seven separate Random Forest models. One dedicated entirely to Temperature, one to AQI, one to Dust, etc. Each model learns how its specific variable behaves based on the previous 30-minute window of all combined variables.

The Training Phase (Using all 14 Days): The model uses the full 14 days of data, but only to study and learn the rules.

- When the time is 12:00 PM, the temperature usually goes up.
- When AQI is high at 2:00 PM, it usually stays high at 2:30 PM.
- Weekends have less CO2 than weekdays.

Once the AI finishes reading those 14 days, it builds its Random Forest "brain" and completely throws the historical data away.

Step 3: The Recursive Prediction Loop (The "Sliding Window")

To predict 7 days into the future, the code relies on a feedback loop:

1) The Starting Point: It takes the very last known real sensor reading (e.g., today at 12:00 PM).
2) Step 1 Prediction: It feeds that real data into the ML models to predict what the air will look like at 12:30 PM.
3) The Feedback Loop: To predict 1:00 PM, the model no longer has real data. Therefore, it takes its own 12:30 PM prediction and feeds it back into itself as the new input to generate the 1:00 PM prediction.
4) Iteration: This cycle repeats 336 times. The outputs of step N become the inputs for step N+1, chaining together to generate a full 7-day forecast.

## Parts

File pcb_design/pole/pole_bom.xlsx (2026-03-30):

No. | Quantity | Comment | Designator | Footprint | Value | Manufacturer Part | Manufacturer | Supplier Part | Supplier
1 | 4 | 220uF | C1,C1,C1,C1 | CAP-TH_BD6.3-P2.50-D0.5-FD | 220uF | 16V220uF CD288 | HRK(鸿瑞凯电子) | C2960376 | LCSC
2 | 4 | 2.54-1*6P母 | DustSensor,DustSensor,DustSensor,DustSensor | HDR-TH_6P-P2.54-V-F |  | 2.54-1*6P母 | BOOMELE(博穆精密) | C40877 | LCSC
3 | 4 | 2.54-1*8P母环保 | ENS160+ATH21,ENS160+ATH21,ENS160+ATH21,ENS160+ATH21 | HDR-TH_8P-P2.54-V-F_2 |  | 2.54-1*8P母环保 | BOOMELE(博穆精密) | C27438 | LCSC
4 | 8 | PM2.54-1*4 | LCD1,LCD1,LCD1,LCD1,MQ135,MQ135,MQ135,MQ135 | HDR-TH_4P-P2.54-V-F |  | PM2.54-1*4 | ZHOURI(洲日) | C5116530 | LCSC
5 | 4 | 150Ω | R2,R2,R2,R2 | RES-TH_BD2.2-L6.5-P10.50-D0.6 | 150Ω | MF1/4W-150Ω±1% T | CCO(千志电子) | C119307 | LCSC
6 | 4 | WJ500V-5.08-2P | ScrewTerminal,ScrewTerminal,ScrewTerminal,ScrewTerminal | CONN-TH_2P-P5.00_WJ500V-5.08-2P |  | WJ500V-5.08-2P | KANGNEX(康奈克斯电气) | C8465 | LCSC
7 | 4 | HX KCD11-2P-R | Switch1,Switch1,Switch1,Switch1 | SW-TH_2P-L15.0-W10.5-P5.00_KCD11-2P-R |  | HX KCD11-2P-R | hanxia(韩下) | C6917318 | LCSC
8 | 4 | B3F-4055 | Switch2,Switch2,Switch2,Switch2 | KEY-TH_4P-L12.0-W12.0-P5.00-LS13.4-EH |  | B3F-4055 | OMRON(欧姆龙) | C84931 | LCSC
9 | 8 | ZX-PM2.54-1-22PY | U1,U1,U1,U1,U2,U2,U2,U2 | HDR-TH_22P-P2.54-V-F |  | ZX-PM2.54-1-22PY | Megastar(兆星) | C7499337 | LCSC

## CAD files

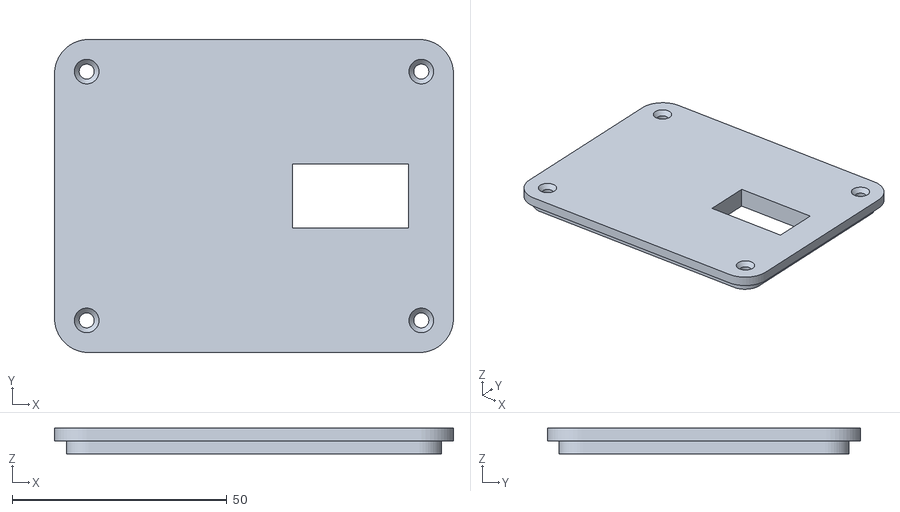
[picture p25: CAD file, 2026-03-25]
3d_designs/Wearable_Lid.stl
93.0 x 73.0 x 6.00

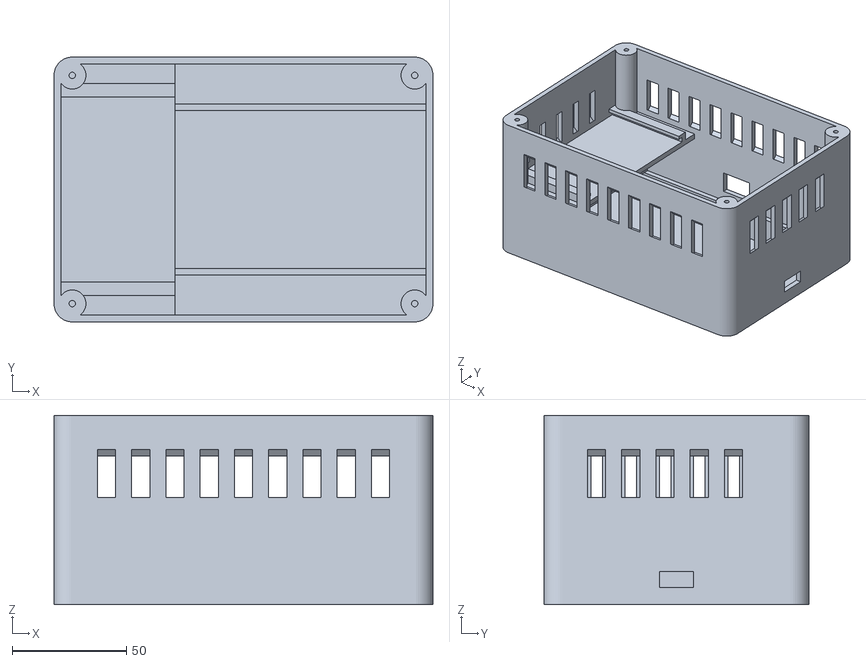
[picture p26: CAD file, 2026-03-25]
3d_designs/Pole_Box.stl
166.0 x 116.0 x 83.0

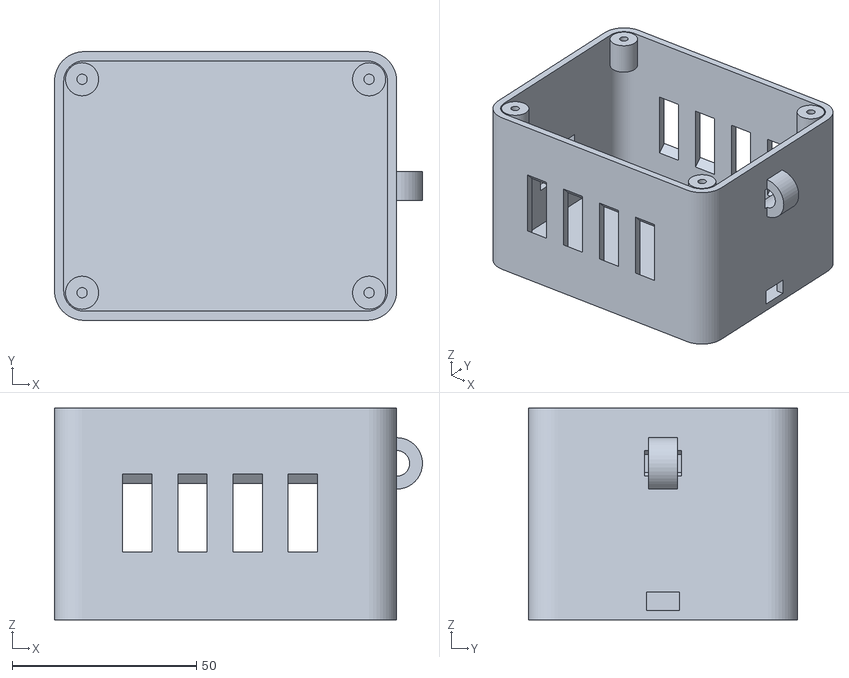
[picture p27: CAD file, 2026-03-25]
3d_designs/Wearable_Box.stl
100.0 x 73.0 x 57.5

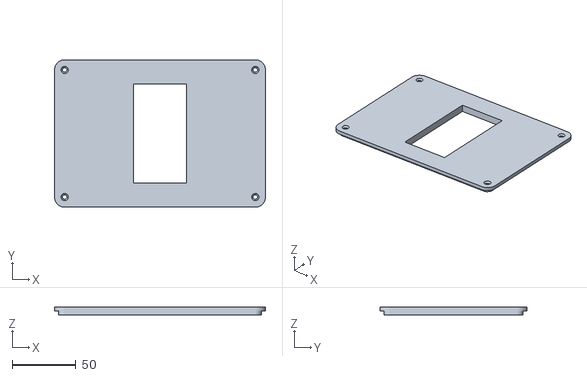
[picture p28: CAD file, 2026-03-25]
3d_designs/Pole_Lid.stl
166.0 x 116.0 x 6.00

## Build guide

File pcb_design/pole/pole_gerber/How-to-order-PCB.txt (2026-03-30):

How to Order PCB

Please refer to:
https://prodocs.easyeda.com/en/pcb/order-order-pcb/index.html

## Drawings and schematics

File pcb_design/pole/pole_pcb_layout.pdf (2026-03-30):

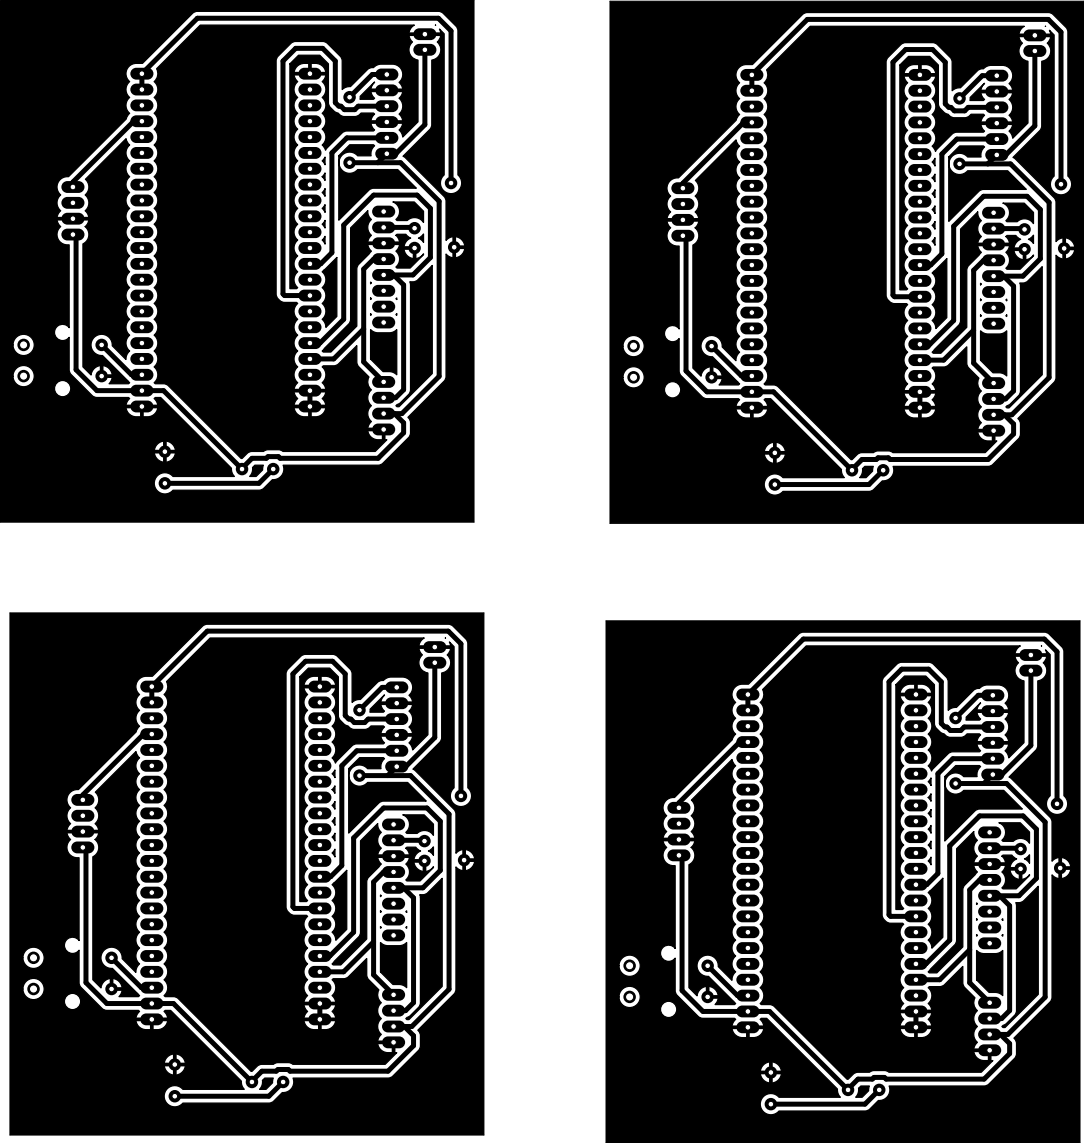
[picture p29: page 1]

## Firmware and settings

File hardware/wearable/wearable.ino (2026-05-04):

#include <WiFi.h>
#include <HTTPClient.h>
#include <ArduinoJson.h>
#include <WiFiClientSecure.h>
#include <time.h>
#include <Wire.h>
#include <SparkFun_ENS160.h>
#include <Adafruit_AHTX0.h>
#include <Adafruit_GFX.h>
#include <Adafruit_SSD1306.h>

/* ---------- OLED Display ---------- */
#define SCREEN_WIDTH 128
#define SCREEN_HEIGHT 64
#define OLED_RESET    -1 
#define SCREEN_ADDRESS 0x3C 

Adafruit_SSD1306 display(SCREEN_WIDTH, SCREEN_HEIGHT, &Wire, OLED_RESET);

/* ---------- WiFi ---------- */
#define WIFI_SSID "YOUR_WIFI_NAME"
#define WIFI_PASS "YOUR_WIFI_PASSWORD"

/* ---------- Firebase ---------- */
#define API_KEY    "YOUR_API_KEY"
#define PROJECT_ID "YOUR_PROJECT_ID"

/* ---------- Battery Monitoring ---------- */
#define BATTERY_PIN 6  // GPIO6 (ADC1_CH7) for battery voltage divider
#define ADC_RESOLUTION 4095.0  // 12-bit ADC
#define ADC_REF_VOLTAGE 3.3    // Reference voltage in volts
#define VOLTAGE_DIVIDER_RATIO 6.639  // Two equal resistors = ratio of 2

// Battery voltage thresholds (adjust based on your battery type)
// For LiPo: 4.2V = 100%, 3.7V = ~50%, 3.0V = 0%
#define BATTERY_MAX_VOLTAGE 4.2
#define BATTERY_MIN_VOLTAGE 3.2

/* ---------- Touch Sensor for Deep Sleep ---------- */
#define TOUCH_PIN 13  // GPIO 13 for TTP223 touch sensor

/* ---------- Sensors ---------- */
SparkFun_ENS160 ens160;
Adafruit_AHTX0 aht;

/* ---------- Timing ---------- */
unsigned long lastRead = 0;
const unsigned long READ_INTERVAL = 60000;

/* ---------- Touch Control ---------- */
unsigned long lastTouchTime = 0;
const unsigned long TOUCH_DEBOUNCE = 500;  // 500ms debounce
int lastTouchState = LOW;

/* ---------- RTC Memory (survives deep sleep) ---------- */
RTC_DATA_ATTR int bootCount = 0;  // Counts how many times we've woken up

String idToken = "";

/* ---------- Battery Functions ---------- */

// Read battery voltage from ADC
float readBatteryVoltage() {
  // Take multiple readings for accuracy
  int adcSum = 0;
  const int numReadings = 10;
  
  for (int i = 0; i < numReadings; i++) {
    adcSum += analogRead(BATTERY_PIN);
    delay(10);
  }
  
  int adcValue = adcSum / numReadings;
  
  // Convert ADC value to voltage at the divider (half of battery voltage)
  float dividerVoltage = (adcValue / ADC_RESOLUTION) * ADC_REF_VOLTAGE;
  
  // Calculate actual battery voltage (multiply by divider ratio)
  float batteryVoltage = dividerVoltage * VOLTAGE_DIVIDER_RATIO;
  
  return batteryVoltage;
}

// Calculate battery percentage
int getBatteryPercentage(float voltage) {
  if (voltage >= BATTERY_MAX_VOLTAGE) return 100;
  if (voltage <= BATTERY_MIN_VOLTAGE) return 0;
  
  // Linear interpolation between min and max
  float percentage = ((voltage - BATTERY_MIN_VOLTAGE) / 
                     (BATTERY_MAX_VOLTAGE - BATTERY_MIN_VOLTAGE)) * 100.0;
  
  return constrain((int)percentage, 0, 100);
}

// Get battery icon character based on percentage
String getBatteryIcon(int percentage) {
  if (percentage >= 80) return "====";
  else if (percentage >= 60) return "=== ";
  else if (percentage >= 40) return "==  ";
  else if (percentage >= 20) return "=   ";
  else return "!   "; // Low battery warning
}

/* ---------- Time ---------- */
String isoTimestampUTC() {
  time_t now;
  time(&now);
  struct tm utc;
  gmtime_r(&now, &utc);
  char buf[30];
  strftime(buf, sizeof(buf), "%Y-%m-%dT%H:%M:%SZ", &utc);
  return String(buf);
}

String localTimestamp() {
  struct tm t;
  getLocalTime(&t);
  char buf[30];
  strftime(buf, sizeof(buf), "%Y-%m-%d %H:%M:%S", &t);
  return String(buf);
}

String minuteDocId() {
  struct tm t;
  getLocalTime(&t);
  char buf[20];
  strftime(buf, sizeof(buf), "%Y%m%d_%H%M", &t);
  return String(buf);
}

/* ---------- Run Score Calculation ---------- */

// Convert eCO2 to score (0-100)
float getECO2Score(int eco2) {
  // Lower CO2 is better
  // < 400 ppm = 100, 400-1000 = linear decrease, > 5000 = 0
  if (eco2 < 400) return 100.0;
  if (eco2 > 5000) return 0.0;
  return max(0.0, 100.0 - ((eco2 - 400) / 46.0));
}

// Convert TVOC to score (0-100)
float getTVOCScore(int tvoc) {
  // Lower TVOC is better
  // < 65 ppb = 100, 65-220 = good, 220-660 = moderate, > 2200 = 0
  if (tvoc < 65) return 100.0;
  if (tvoc > 2200) return 0.0;
  return max(0.0, 100.0 - ((tvoc - 65) / 21.35));
}

// Convert Temperature to score (0-100)
float getTempScore(float temp) {
  // Optimal running temp: 10-20°C
  // 10-20°C = 100, decrease outside this range
  if (temp >= 10 && temp <= 20) return 100.0;
  if (temp < 0 || temp > 40) return 0.0;
  
  if (temp < 10) {
    // 0°C = 50, 10°C = 100
    return 50.0 + (temp * 5.0);
  } else {
    // 20°C = 100, 40°C = 0
    return max(0.0, 100.0 - ((temp - 20) * 5.0));
  }
}

// Convert Humidity to score (0-100)
float getHumScore(float hum) {
  // Optimal humidity: 40-60%
  // 40-60% = 100, decrease outside this range
  if (hum >= 40 && hum <= 60) return 100.0;
  if (hum < 10 || hum > 90) return 0.0;
  
  if (hum < 40) {
    // 10% = 0, 40% = 100
    return (hum - 10) * 3.33;
  } else {
    // 60% = 100, 90% = 0
    return max(0.0, 100.0 - ((hum - 60) * 3.33));
  }
}

// Calculate Runner AQI (0-100)
float calculateRunnerAQI(int eco2, int tvoc, float temp, float hum) {
  float eco2_score = getECO2Score(eco2);
  float tvoc_score = getTVOCScore(tvoc);

  // 2. DOMINANT POLLUTANT: Health is dictated strictly by the WORST metric
  float health_aqi = min(eco2_score, tvoc_score);

  float temp_score = getTempScore(temp);
  float hum_score = getHumScore(hum);

  // Comfort is a blend of heat and humidity
  float comfort_score = (temp_score * 0.6) + (hum_score * 0.4); 
  
  // 4. Apply Comfort as a Scaling Penalty
  // Poor comfort degrades a runner's performance even in perfect air,
  // but perfect comfort cannot magically fix toxic air.
  // This multiplier ranges from 0.5 (terrible comfort) to 1.0 (perfect comfort).
  float comfort_multiplier = 0.5 + (comfort_score / 200.0);
  
  float runner_aqi = health_aqi * comfort_multiplier;

  return runner_aqi;
}

// Get status based on Runner AQI
String getStatus(float score) {
  if (score >= 85) return "SAFE";
  else if (score >= 70) return "LOW RISK";
  else if (score >= 50) return "CAUTION";
  else if (score >= 30) return "UNSAFE";
  else return "DANGEROUS";
}

/* ---------- Firebase Auth ---------- */
void getToken() {
  WiFiClientSecure client;
  client.setInsecure();
  HTTPClient http;

  http.begin(client,
    "https://identitytoolkit.googleapis.com/v1/accounts:signUp?key=" API_KEY);
  http.addHeader("Content-Type", "application/json");

  if (http.POST("{}") > 0) {
    StaticJsonDocument<512> doc;
    deserializeJson(doc, http.getString());
    idToken = doc["idToken"].as<String>();
  }
  http.end();
}

/* ---------- Firestore Write ---------- */
void sendToFirestore(
  float t, float h,
  int aqi, int eco2, int tvoc,
  float runner_aqi, float batteryVoltage, int batteryPercent
) {
  WiFiClientSecure client;
  client.setInsecure();
  HTTPClient http;

  String url =
    "https://firestore.googleapis.com/v1/projects/" PROJECT_ID
    "/databases/(default)/documents/sensor_data/esp32_0/readings/"
    + minuteDocId()
    + "?access_token=" + idToken;

  StaticJsonDocument<512> doc;

  doc["fields"]["temperature"]["doubleValue"] = t;
  doc["fields"]["humidity"]["doubleValue"] = h;
  doc["fields"]["aqi"]["integerValue"] = aqi;
  doc["fields"]["eco2"]["integerValue"] = eco2;
  doc["fields"]["tvoc"]["integerValue"] = tvoc;
  doc["fields"]["runner_aqi"]["doubleValue"] = runner_aqi;
  doc["fields"]["battery_voltage"]["doubleValue"] = batteryVoltage;
  doc["fields"]["battery_percent"]["integerValue"] = batteryPercent;
  doc["fields"]["timestamp"]["stringValue"] = isoTimestamp();

  String json;
  serializeJson(doc, json);

  http.begin(client, url);
  http.addHeader("Content-Type", "application/json");
  http.sendRequest("PATCH", json);
  http.end();
}

/* ---------- Draw Battery Icon (top-right) ---------- */
void drawBatteryIcon(int percent) {
  // Battery body: 22x10 px, top-right corner (x=104, y=1)
  const int bx = 104, by = 1, bw = 22, bh = 10;

  // Outer rectangle
  display.drawRect(bx, by, bw, bh, SSD1306_WHITE);

  // Battery tip (nub) on the right side
  display.fillRect(bx + bw, by + 3, 2, 4, SSD1306_WHITE);

  // Fill level (leave 1px padding inside)
  int fillW = map(constrain(percent, 0, 100), 0, 100, 0, bw - 4);
  if (fillW > 0) {
    display.fillRect(bx + 2, by + 2, fillW, bh - 4, SSD1306_WHITE);
  }
}

/* ---------- Display Runner Dashboard ---------- */
void drawRunnerDashboard(float runScore, float temp, float hum, int eco2, int tvoc, 
                        float batteryVoltage, int batteryPercent) {
  display.clearDisplay();

  // ========== TOP RIGHT: Battery icon + percentage ==========
  // Percentage text (right-aligned before icon)
  display.setTextSize(1);
  char batStr[5];
  snprintf(batStr, sizeof(batStr), "%d%%", batteryPercent);
  int textX = 100 - (strlen(batStr) * 6);  // 6px per char at textSize 1
  display.setCursor(textX, 2);
  display.print(batStr);

  // Draw the battery icon
  drawBatteryIcon(batteryPercent);

  // Separator line
  display.drawFastHLine(0, 13, SCREEN_WIDTH, SSD1306_WHITE);
  
  // ========== MAIN SECTION: Run Score ==========
  display.setTextSize(1);
  display.setCursor(2, 16);
  display.print("Run Score");

  // Large score number
  display.setTextSize(3);
  int scoreInt = (int)runScore;
  if (scoreInt < 10) {
    display.setCursor(50, 26);
  } else if (scoreInt < 100) {
    display.setCursor(40, 26);
  } else {
    display.setCursor(30, 26);
  }
  display.print(scoreInt);
    
  // ========== BOTTOM: Status ==========
  display.setTextSize(1);
  display.setCursor(2, 50);
  display.print("Status: ");
  
  String status = getStatus(runScore);
  display.setTextSize(1);
  display.setCursor(50, 50);
  display.print(status);
  
  // Progress bar
  int barWidth = map(runScore, 0, 100, 10, 126);
  display.fillRect(2, 62, barWidth, 2, SSD1306_WHITE);
  
  display.display();
}

/* ---------- Deep Sleep Functions ---------- */

// Print the wakeup reason
void printWakeupReason() {
  esp_sleep_wakeup_cause_t wakeup_reason;
  wakeup_reason = esp_sleep_get_wakeup_cause();

  switch(wakeup_reason) {
    case ESP_SLEEP_WAKEUP_EXT0: 
      Serial.println("Wakeup caused by external signal using RTC_IO (Touch Sensor)");
      break;
    case ESP_SLEEP_WAKEUP_EXT1: 
      Serial.println("Wakeup caused by external signal using RTC_CNTL");
      break;
    case ESP_SLEEP_WAKEUP_TIMER: 
      Serial.println("Wakeup caused by timer");
      break;
    case ESP_SLEEP_WAKEUP_TOUCHPAD: 
      Serial.println("Wakeup caused by touchpad");
      break;
    case ESP_SLEEP_WAKEUP_ULP: 
      Serial.println("Wakeup caused by ULP program");
      break;
    default: 
      Serial.printf("Wakeup was not caused by deep sleep: %d\n", wakeup_reason);
      break;
  }
}

// Enter deep sleep mode
void enterDeepSleep() {
  Serial.println("=============================");
  Serial.println("ENTERING DEEP SLEEP MODE");
  Serial.println("Touch sensor to wake up...");
  Serial.println("=============================");
  
  // Read battery one more time before sleep
  float batteryV = readBatteryVoltage();
  int batteryP = getBatteryPercentage(batteryV);
  
  // Display sleep message
  display.clearDisplay();
  display.setTextSize(1);
  display.setCursor(10, 5);
  display.println("   SLEEP MODE");
  display.println("");
  display.println("  Touch sensor");
  display.println("   to wake up");
  display.println("");
  display.printf("  Boots: %d", bootCount);
  display.println("");
  display.printf("  Batt: %d%% %.2fV", batteryP, batteryV);
  display.display();
  
  delay(2000);  // Show message for 2 seconds
  
  // Turn off display
  display.clearDisplay();
  display.display();
  
  // Configure wake-up source
  // Wake up when GPIO 13 goes HIGH (touch sensor is touched)
  esp_sleep_enable_ext0_wakeup(GPIO_NUM_13, 1);
  
  // Optional: Add timer wakeup as backup (e.g., wake every 10 minutes)
  // esp_sleep_enable_timer_wakeup(10 * 60 * 1000000ULL);  // 10 minutes
  
  Serial.flush();  // Wait for serial to finish
  
  // Enter deep sleep
  esp_deep_sleep_start();
  
  // Code never reaches here - ESP32 resets on wake
}

/* ---------- Touch Sensor Handling ---------- */

// Check if touch sensor is pressed (with debouncing)
bool isTouchPressed() {
  int currentState = digitalRead(TOUCH_PIN);
  unsigned long currentTime = millis();
  
  // Check if state changed and debounce time passed
  if (currentState == HIGH && lastTouchState == LOW) {
    if (currentTime - lastTouchTime > TOUCH_DEBOUNCE) {
      lastTouchTime = currentTime;
      lastTouchState = currentState;
      return true;
    }
  }
  
  lastTouchState = currentState;
  return false;
}

/* ---------- Setup ---------- */
void setup() {
  Serial.begin(115200);
  delay(1000);
  
  // Configure ADC for battery monitoring
  analogReadResolution(12);  // 12-bit resolution (0-4095)
  analogSetAttenuation(ADC_11db);  // Full range: 0-3.3V
  pinMode(BATTERY_PIN, INPUT);
  Serial.println("Battery monitoring configured on GPIO6");
  
  // Increment boot count
  bootCount++;
  
  Serial.println("=================================");
  Serial.println("=== RUNNER AQI SYSTEM (v2.1) ===");
  Serial.println("=== With Battery Monitoring  ===");
  Serial.println("=================================");
  Serial.printf("Boot count: %d\n", bootCount);
  
  // Print wakeup reason
  printWakeupReason();
  
  // Read initial battery level
  float initialBatteryV = readBatteryVoltage();
  int initialBatteryP = getBatteryPercentage(initialBatteryV);
  Serial.printf("Battery: %.2fV (%d%%)\n", initialBatteryV, initialBatteryP);
  
  // Configure touch sensor pin
  pinMode(TOUCH_PIN, INPUT);
  Serial.printf("Touch sensor configured on GPIO %d\n", TOUCH_PIN);
  
  Wire.begin(8, 9); 
  Serial.println("I2C Initialized");

  // Init OLED
  if(!display.begin(SSD1306_SWITCHCAPVCC, SCREEN_ADDRESS)) {
    Serial.println(F("SSD1306 allocation failed"));
    for(;;); 
  }
  Serial.println("OLED Initialized");
  
  display.clearDisplay();
  display.setTextColor(SSD1306_WHITE);

  // Project name - large, centered
  display.setTextSize(2);
  display.setCursor(4, 4);
  display.print("Smart");
  display.setCursor(4, 22);
  display.print("RunSense");

  // Divider
  display.drawFastHLine(0, 43, SCREEN_WIDTH, SSD1306_WHITE);

  // Sub-info row
  display.setTextSize(1);
  display.setCursor(0, 47);
  display.printf("v2.1  Boot#%d", bootCount);
  display.setCursor(0, 57);
  display.printf("Batt: %d%%  %.2fV", initialBatteryP, initialBatteryV);

  display.display();
  Serial.println("OLED Display Updated");

  Serial.print("Connecting to WiFi: ");
  Serial.println(WIFI_SSID);
  
  WiFi.begin(WIFI_SSID, WIFI_PASS);
  int attempts = 0;
  while (WiFi.status() != WL_CONNECTED) {
    delay(500);
    Serial.print(".");
    attempts++;
    
    if(attempts > 40) { // 20 seconds timeout
      Serial.println("\nWiFi connection failed!");
      display.clearDisplay();
      display.setCursor(0, 10);
      display.println("WiFi Failed!");
      display.println("");
      display.println("Touch to retry");
      display.println("");
      display.println("Check:");
      display.println("- SSID/Password");
      display.display();

      // Wait for touch sensor to retry WiFi instead of hard-locking
      Serial.println("Touch sensor to retry WiFi...");
      while (true) {
        if (isTouchPressed()) {
          Serial.println("Touch detected — retrying WiFi...");
          display.clearDisplay();
          display.setCursor(0, 10);
          display.println("Retrying WiFi...");
          display.display();
          WiFi.disconnect(true);
          delay(500);
          WiFi.begin(WIFI_SSID, WIFI_PASS);
          attempts = 0;  // Reset attempt counter to re-enter outer while loop
          break;         // Break inner loop, outer while(WiFi!=connected) resumes
        }
        delay(50); // Small yield to avoid watchdog trigger
      }
    }
  }
  
  Serial.println("\nWiFi Connected!");
  display.clearDisplay();
  display.setCursor(0, 10);
  display.println("WiFi Connected!");
  display.println("");
  display.print("IP: ");
  display.println(WiFi.localIP());
  display.display();

  configTime(5.5 * 3600, 0, "pool.ntp.org");
  
  delay(1000);
  display.clearDisplay();
  display.setCursor(0, 10);
  display.println("Getting Auth Token...");
  display.display();
  
  getToken();

  // Init Sensors
  display.clearDisplay();
  display.setCursor(0, 10);
  display.println("Initializing Sensors...");
  display.display();
  
  if (!aht.begin()) {
    Serial.println("AHT Sensor failed");
    display.clearDisplay();
    display.setCursor(0, 10);
    display.println("ERROR:");
    display.println("AHT Sensor Failed!");
    display.display();
    delay(3000);
  } else {
    Serial.println("AHT Sensor OK");
  }
  
  if (!ens160.begin()) {
    Serial.println("ENS160 Sensor failed");
    display.clearDisplay();
    display.setCursor(0, 10);
    display.println("ERROR:");
    display.println("ENS160 Sensor Failed!");
    display.display();
    delay(3000);
  } else {
    Serial.println("ENS160 Sensor OK");
  }
  
  ens160.setOperatingMode(SFE_ENS160_STANDARD);

  display.clearDisplay();
  display.setCursor(0, 15);
  display.println("   System Ready!");
  display.println("");
  display.println(" Touch to Sleep");
  display.display();
  
  Serial.println("\n>>> Touch sensor to enter deep sleep <<<\n");
  
  delay(2000);
  lastRead = millis() - READ_INTERVAL;
}

/* ---------- Loop ---------- */
void loop() {
  if (idToken == "") return;

  // ========== TOUCH SENSOR CHECK ==========
  // Check for touch to enter deep sleep
  if (isTouchPressed()) {
    Serial.println("\n>>> TOUCH DETECTED - Entering Deep Sleep <<<\n");
    delay(100);  // Small delay for debouncing
    enterDeepSleep();  // Never returns
  }
  
  // ========== SENSOR READING ==========
  if (millis() - lastRead >= READ_INTERVAL) {
    lastRead = millis();

    /* ---- Battery Reading ---- */
    float batteryVoltage = readBatteryVoltage();
    int batteryPercent = getBatteryPercentage(batteryVoltage);

    /* ---- Temp & Hum (AHT) ---- */
    sensors_event_t hum, temp;
    aht.getEvent(&hum, &temp);

    /* ---- ENS160 ---- */
    ens160.setTempCompensation(temp.temperature);
    ens160.setRHCompensation(hum.relative_humidity);

    int aqi  = ens160.getAQI();
    int eco2 = ens160.getECO2();
    int tvoc = ens160.getTVOC();

    /* ---- Calculate Runner AQI ---- */
    float runnerScore = calculateRunnerAQI(eco2, tvoc, temp.temperature, hum.relative_humidity);
    
    /* ---- Display Update ---- */
    drawRunnerDashboard(runnerScore, temp.temperature, hum.relative_humidity, 
                       eco2, tvoc, batteryVoltage, batteryPercent);

    /* ---- Serial Debug ---- */
    Serial.println("=============================");
    Serial.println("RUNNER AQI REPORT");
    Serial.println(isoTimestamp());
    Serial.println("-----------------------------");
    Serial.printf("Battery: %.2fV (%d%%)\n", batteryVoltage, batteryPercent);
    Serial.println("-----------------------------");
    Serial.printf("eCO2: %d ppm (Score: %.1f)\n", eco2, getECO2Score(eco2));
    Serial.printf("TVOC: %d ppb (Score: %.1f)\n", tvoc, getTVOCScore(tvoc));
    Serial.printf("Temp: %.1f C (Score: %.1f)\n", temp.temperature, getTempScore(temp.temperature));
    Serial.printf("Humidity: %.1f %% (Score: %.1f)\n", hum.relative_humidity, getHumScore(hum.relative_humidity));
    Serial.println("-----------------------------");
    Serial.printf("RUNNER SCORE: %.1f\n", runnerScore);
    Serial.printf("STATUS: %s\n", getStatus(runnerScore).c_str());
    Serial.println("=============================\n");

    sendToFirestore(
      temp.temperature,
      hum.relative_humidity,
      aqi,
      eco2,
      tvoc,
      runnerScore,
      batteryVoltage,
      batteryPercent
    );
  }
}

/* ---------- NOTES ON BATTERY VOLTAGE DIVIDER ---------- */
/*
 * Hardware Setup:
 * - Battery (+) ---- 100kΩ ---- GPIO6 (ADC) ---- 100kΩ ---- GND
 * 
 * The voltage divider creates Vout = Vin × (R2 / (R1 + R2))
 * With equal resistors: Vout = Vin × 0.5
 * 
 * Maximum safe ADC input: 3.3V
 * Maximum battery voltage measurable: 3.3V × 2 = 6.6V
 * 
 * Calibration Tips:
 * 1. Measure your actual battery voltage with a multimeter
 * 2. Compare with the voltage reported by the code
 * 3. Adjust VOLTAGE_DIVIDER_RATIO if needed (actual ratio may vary due to resistor tolerance)
 * 4. Adjust BATTERY_MAX_VOLTAGE and BATTERY_MIN_VOLTAGE based on your battery type:
 *    - LiPo: 4.2V (full) to 3.0V (empty)
 *    - Li-ion: 4.2V (full) to 3.0V (empty)
 *    - 3.7V LiPo: Use values above
 * 
 * To calibrate the voltage divider ratio:
 * 1. Measure real battery voltage with multimeter: e.g., 4.05V
 * 2. Note the voltage displayed by the code (before calibration): e.g., 1.22V
 * 3. Calculate correction: VOLTAGE_DIVIDER_RATIO = (4.05 / 1.22) × 2.0 = 6.639
 *    (multiply by old ratio of 2.0 since the base divider uses equal resistors)
 * 4. Update the #define VOLTAGE_DIVIDER_RATIO value
 * 
 * *** CALIBRATED VALUES (your hardware) ***
 * Multimeter reading : 4.05V
 * Code displayed     : 1.22V  (with old ratio = 2.0)
 * Calibrated ratio   : 6.639  ✓ (currently applied)
 */

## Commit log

2026-03-30 Rename folders to follow snake_case naming conventions
    [Pole_Box.stl, Pole_Lid.stl, Wearable_Box.stl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]
2026-03-30 Renamed Sensors folder to lowercase sensors
2026-03-30 Add complete PCB design files for the smart pole
    [Drill_NPTH_Through.DRL, Drill_PTH_Through.DRL, Gerber_BoardOutlineLayer.GKO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]
2026-03-30 Add 3D model (OBJ) and color materials (MTL) for the pole PCB
2026-03-30 Upload smaller 3D model for live preview
    [pole_3d.obj]
2026-05-04 Add source code and documentation of the wearable device, update README
2026-05-04 Add schematic, update README
